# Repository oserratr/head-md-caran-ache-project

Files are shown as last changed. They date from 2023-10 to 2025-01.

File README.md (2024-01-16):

# Future of Drawing - Discovery Process

Discovery est un jeu qui donne un nouveau regard sur la pratique du dessin. Guidé par le sens du toucher, il explore la collaboration entre l’objet et le joueur dans un processus de création.

# Process

## 2023-10-19 to 2023-11-01

*Quelques mots clés*
**Expérience sensorielle - Narration - Liberté d'interprétation**

### Point de départ

J'ai commencé a me demander ce que "AI Assistant" m'évoque dans le projet via une mindmap.
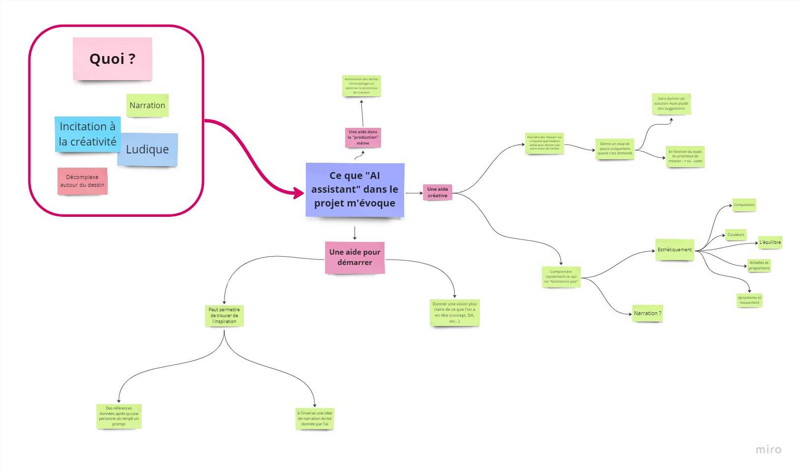
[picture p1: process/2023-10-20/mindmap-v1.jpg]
mindmap


### Public

QUI?
Personnes voulant apprendre, mais stress de ne pas le faire de la "bonne façon" (selon une idée préconçue du dessin),
Complexe par apport a certaines maîtrises du dessin,

POURQUOI?
Rendre le dessin accessible
Décomplexer autour de la pratique du dessin
Expérience sensorielle différente

CONTEXTE
Dans un cours d’initiation au dessin,
Dans un moment calme, chez soi

Le brainstorming m'a permis d'établir un plan de recherche de 3 différentes façons.

### Recherches en ligne sur les pratiques du dessin

**Quels sont les fondamentaux de la pratique du dessin ?**

Sur reddit et d’autre pages web, ont trouve différentes listes que la communauté active sur la pratique du dessin donne en guise de “guide” pour débutant : proportions, couleurs, perspective, anatomie, lumière, volume...

Mais également une distinction de l’apprentissage du dessin traditionnel (papier) et digital : la volonté de structurer son apprentissage, d’apprendre “proprement” la pratique du dessin, sont des éléments récurrents que je retrouve dans les témoignages sur reddit. Ces personnes sont néanmoins limitées sur les moyens techniques, etc...

Une question récurrente est aussi amenée par les internautes a propos d’un certain “ordre” a respecter dans l’apprentissage.

**Quels sont les peurs par apport a la pratique du dessin ?**

Sur la partie focalisé sur les témoignages de personnes se mettant la pression pour faire quelque chose de beau et de la bonne manière j’ai pu remarqué des éléments récurrents : 
- Volonté d’impressionner les gens, d’être validé par la   communauté artistique
- Peu de confiance en soi, comparaison avec l’entourage ou autres artistes qui peu démotiver, pense que son évolution n’est pas assez grande, attente d’un certain niveau considéré par la personne comme étant le “minimum”
- Peur de finir une œuvre et d’échouer, de ne pas être a la hauteur des attentes en therme d’esthétique et de technique, refuse catégoriquement de se lancer pour ne pas produire de “mauvaises choses” 

**Liens d'articles et forums**
- https://www.reddit.com/r/ArtistLounge/comments/ki3zvz/what_would_be_a_list_of_drawing_fundamentals_and/
- https://homesthetics.net/what-are-the-fundamentals/
- https://www.reddit.com/r/IWantToLearn/comments/4ws0wj/i_was_wondering_about_the_fundamentals_of_drawing/
- https://www.youtube.com/watch?v=qpqEE9yU474&list=PLDHJ4RxK-8Tgt-AmgLSdkgdhjL_RS5wrE
- https://www.reddit.com/r/ArtistLounge/comments/kljwdq/why_am_i_so_bad_at_art/

### Recherches en ligne sur les retours haptiques

Plusieurs types de retours haptiques :
- Simule de façon réaliste l'interaction avec un objet via : la texture, le poids, la résistance, le frottement de l'objet
- Un retour haptique qui limite le mouvement : par exemple dans une simulation de conduite de voiture, un volant qui vas être limité dans la vitesse d'exécution du mouvement
- Un retour haptique "actif" qui vas tout simplement être déclenché par une action/mouvement : par exemple dans les jeux vidéo pendant un combat avec un pnj sensation a chaque collision + ou - fortes

### Expérimentations 1 (2 minutes pour chaques parties)

#### Partie 1 : Dessiner au toucher

Dessiner avec un objet dans la main sans le regarder (uniquement reconnaissance au toucher).

*Observations*
- Dessine en plusieurs étapes : au début la forme globale et ensuite certains détails
- Mouvements plus "décomplexés"
- Pas d'attentes/de déceptions sur le dessin final
- Certaines personnes essayes de trouver quel est l'objet avant de le dessiner
- Certaines vont utiliser en même temps leurs souvenirs et le tactile si il reconnaissent l'objet > Avaient l'air "rassuré"

La plupart des personnes n'ont pas utilisé les 2 minutes.
#### Partie 2 : Dessiner de façon classique

Dessiner avec l'objet devant soi en ayant la possibilité de le manipuler, de le regarder.

*Observations*
- Plus de concentration sur l'objet que sur le dessin
- Volonté de le reproduire en fonction de son positionnement, orientation...
- Volonté d'aller dans les détails de l'objet, d'ajouter des ombrages
- Moins de manipulation de l’objet, concentration sur une seule perspective

La plupart des personnes ont utilisé les 2 minutes.

### Interviews

*Quel est ton rapport au dessin ?*
- L’ensemble des personnes interviewer ont commencé le dessin jeune / très jeune : graffiti, dessin a l’école (maternelle, primaire, etc...), activité ludique pour les enfant, concours de dessin, decalcage
- Arrêt de la pratique du dessin pendant un certain temps (souvent entre le collège/lycée)
- Reprise de la pratique par envie, par ennui,
- Pas évident de trouver son propre style graphique,
- Pression par apport au dessin et aux autres

*A quels moment dessine tu ? Dans que contexte ?*
- Pratique de différentes manières : par ennui, professionnellement,  gribouillages sur n’importe quel feuille, par envie, inspiration du moment, ne se limite pas qu’au dessin mais aux arts créatifs, extérioriser, dessiner des souvenirs, fortes émotions, défis/challenges techniques...

*A quels moment dessine tu ? Dans que contexte ?*
- Quels sont selon toi les "critères conventionnels" pour qu'un dessin soit réussi ? Est-ce que tu essaies de les appliquer? Et pourquoi ?

*A quels moment dessine tu ? Dans que contexte ?*
- Subjectif, pas de dessin réussi ou non : doit plaire d’abord a sois même, pas de catégories spécifiques, dessiner au feeling, être fière de son dessin spontanéité. Définition de ces propres critères.
- Pas de manière de dessiner, sauf dans filière très académique. Liberté, assez fort dans le dessin, chacun peut avoir son style, chacun peut faire comme il l’entend.N’essaye pas d’appliquer ces codes académiques.
- Pour des commandes “professionnelles”, certains critères sont parfois a respecter en fonction de cette dernière : proportions, niveau de réalisme en s’appuyant sur des images de références, bon choix de couleurs, beau ombrages, tracées droits. Exemple de la main : importance du réalisme de sa posture, etc...

*Que ressens tu si ton dessin ne correspond pas à ce que tu envisageais?*
- n’anticipe pas ce qui vas être dessiner, totalement freestyle, toujours les même gribouillis et lettres, pour passer le temps, s’attend souvent au résultat que ça va
être, pas d’étonnement spécifique sur le “résultat final”
- frustrations, déception, perfectionnisme, blocage sur détails, motivation pour s’améliorer, pudique sur le dessin en question...

### Prototypage

*À partir de cartes tirées*
**Roller - Color sensor - Wording - Too eager**

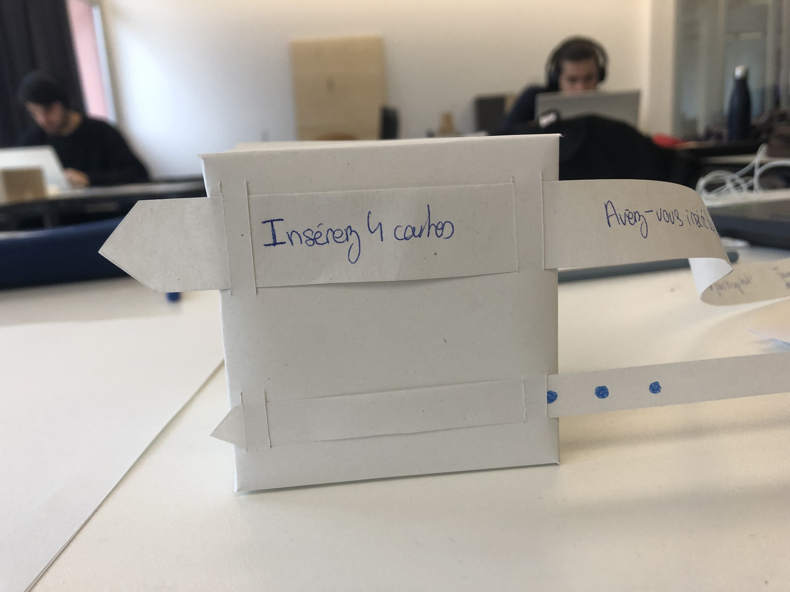
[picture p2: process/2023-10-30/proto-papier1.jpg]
proto1

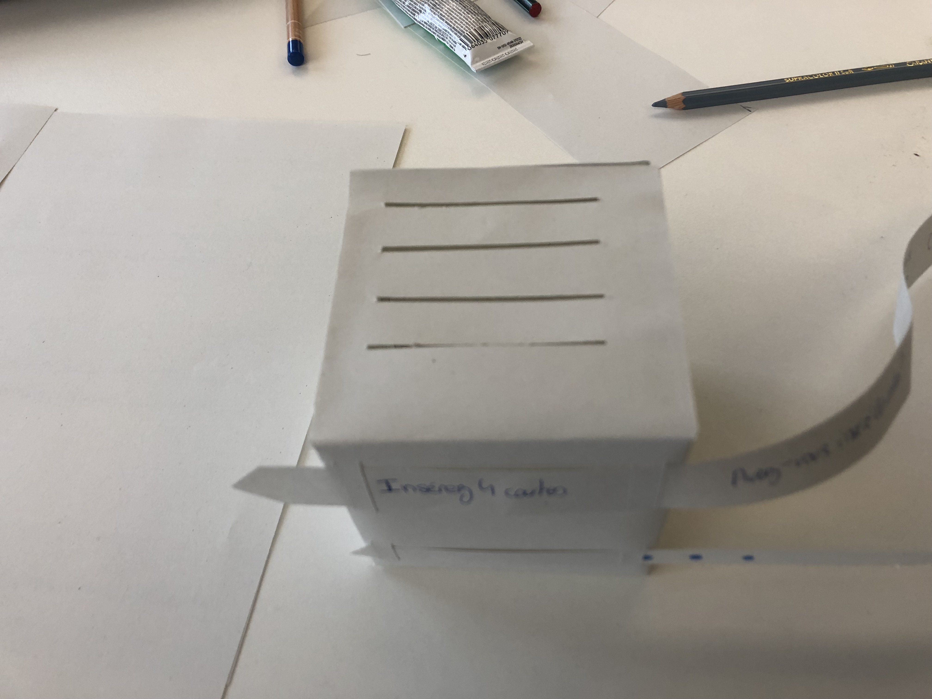
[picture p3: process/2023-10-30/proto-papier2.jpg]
proto2

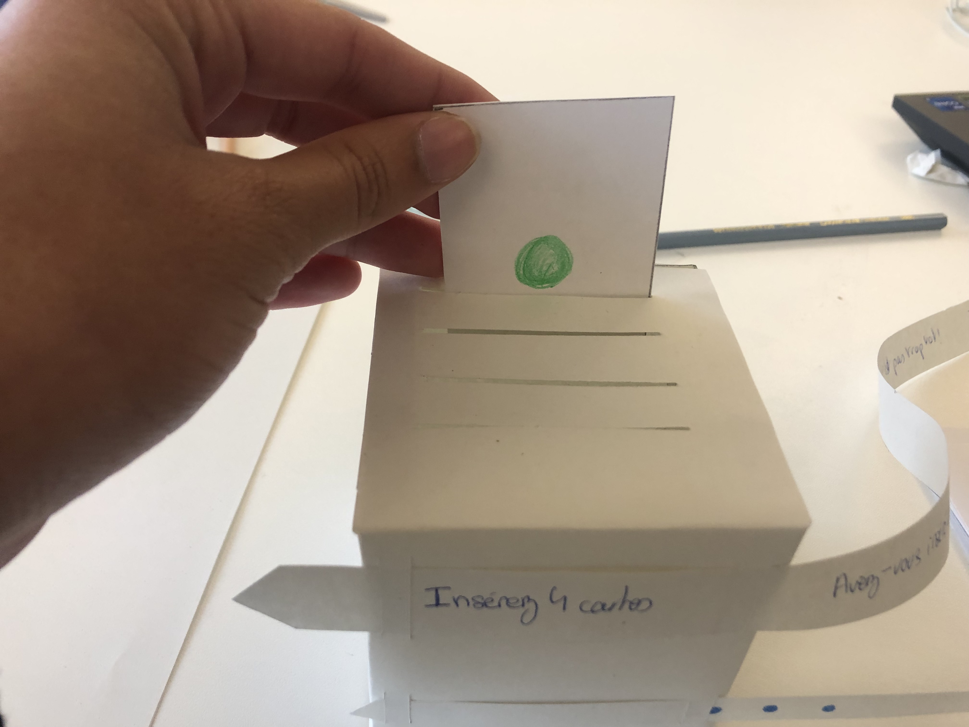
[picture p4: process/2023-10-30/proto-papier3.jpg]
proto3

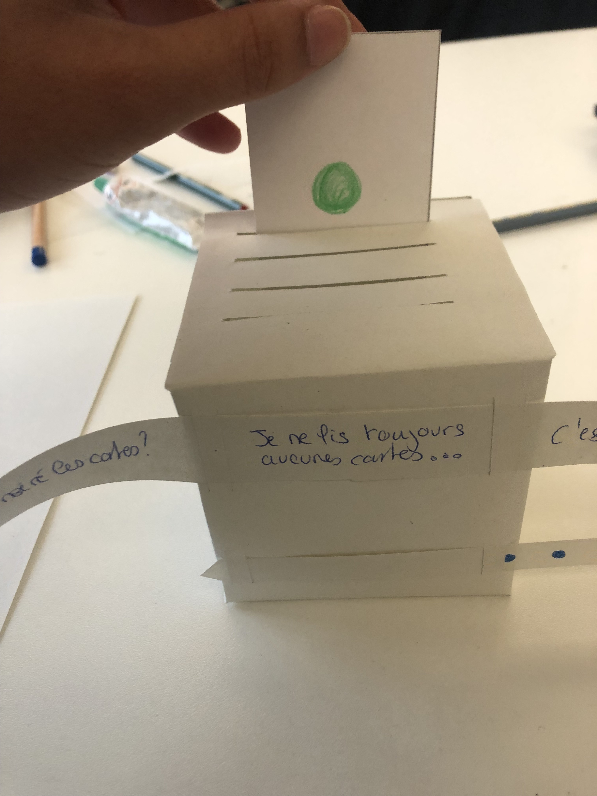
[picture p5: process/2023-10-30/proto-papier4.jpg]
proto4


Un objet qui lirait plusieurs cartes "couleur" que l’on pourrait insérer dans un boîtier qui écrirait sur n'importe quelle surface un poème en le tenant comme un gros rouleau de peinture.

### Premières intentions d'interactions

-> Création de 2 prototypes papiers :

    -> Le premier suite au tirage de cartes (to eager, color sensor, roller, wording) : Un objet qui lirait plusieurs cartes que l’on pourrait insérer dans un boîtier qui ferait de l’écriture en le tenant comme un gros rouleau de peinture. On pourrait choisir via des boutons la typo et au aurait un retour visuel sur les cartes tirées. 

    -> Le deuxième en rapport avec la première intention suite aux recherches menées + cartes tirés (sloppy,pallette): Un objet qui crée une narration de façon aléatoire et divise chaque partie en X en fonction du nombre X de joueur. Chaque joueur dessine sa partie de la narration avec des indices révélé de façon haptique pour faire une grande fresque collaborative. La machine est négligente et peut donner 2 fois la même partie a des joueurs.
1.
*Mots clés*
**Vibrations - Draw - Sloppy - Palette**

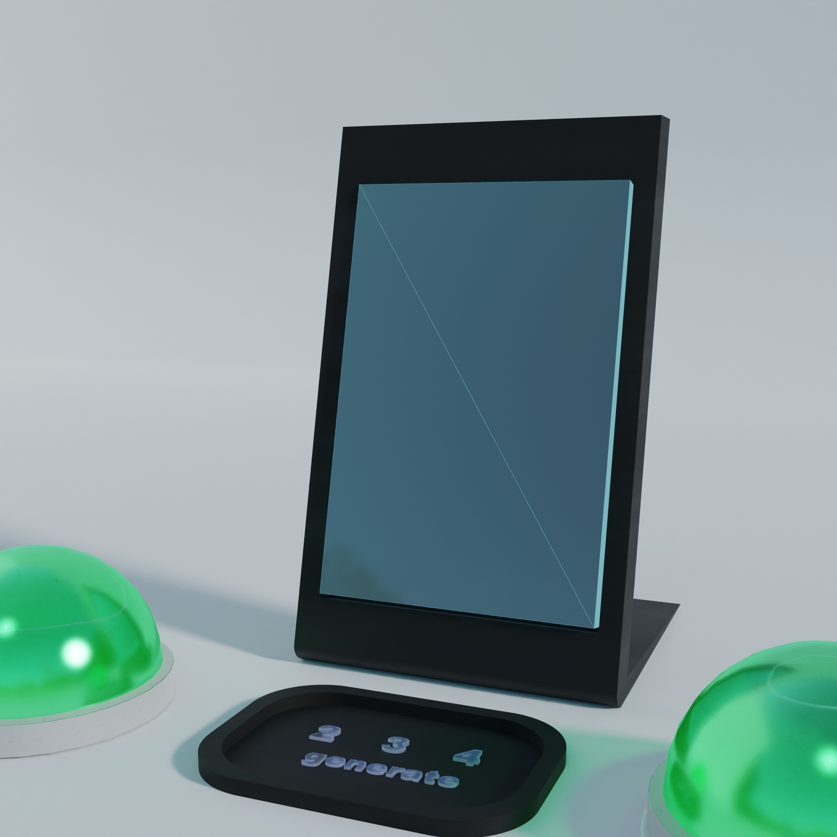
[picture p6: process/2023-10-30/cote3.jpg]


Un objet qui crée une narration de façon aléatoire et divise chaque partie en X en fonction du nombre X de joueur.
Chaque joueur dessine sa partie de la narration avec des indices révélé de façon haptique pour faire une grande fresque collaborative.
La machine est négligente et peut donner 2 fois la même partie a des joueurs(par exemple).

2.
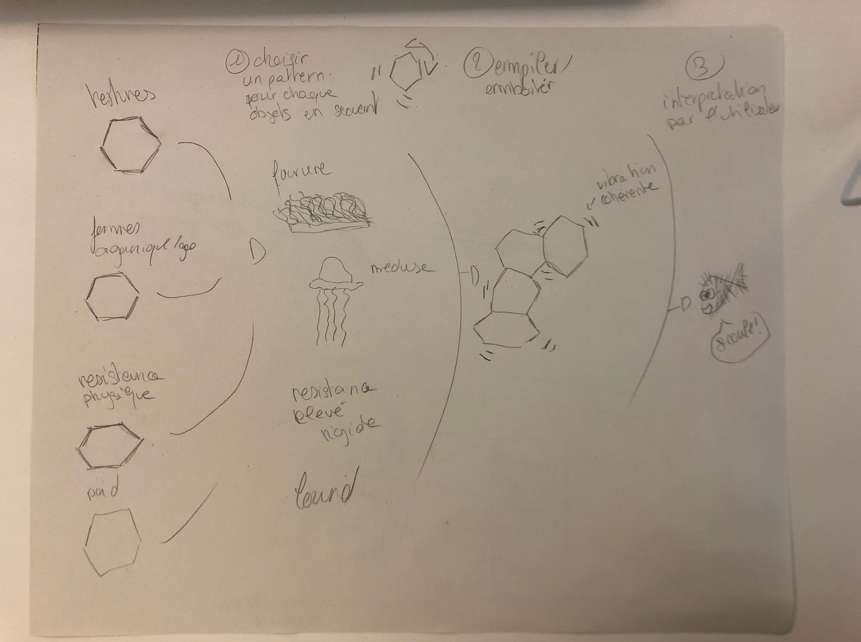
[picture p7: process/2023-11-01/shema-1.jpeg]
proto5


Un objet ayant différents types : texture, poids, forme, résistance / physique. Qui inciterait à l'utilisateur de choisir un partern qui lui plaît dans chaque type d'objet (en le secouant). À la fin du choix, il assemblerait les différents objets pour créer une seule vibration cohérente qui laisserait place à l'interprétation de l'utilisateur, et ainsi, qu'il puisse mettre sur papier.

3.
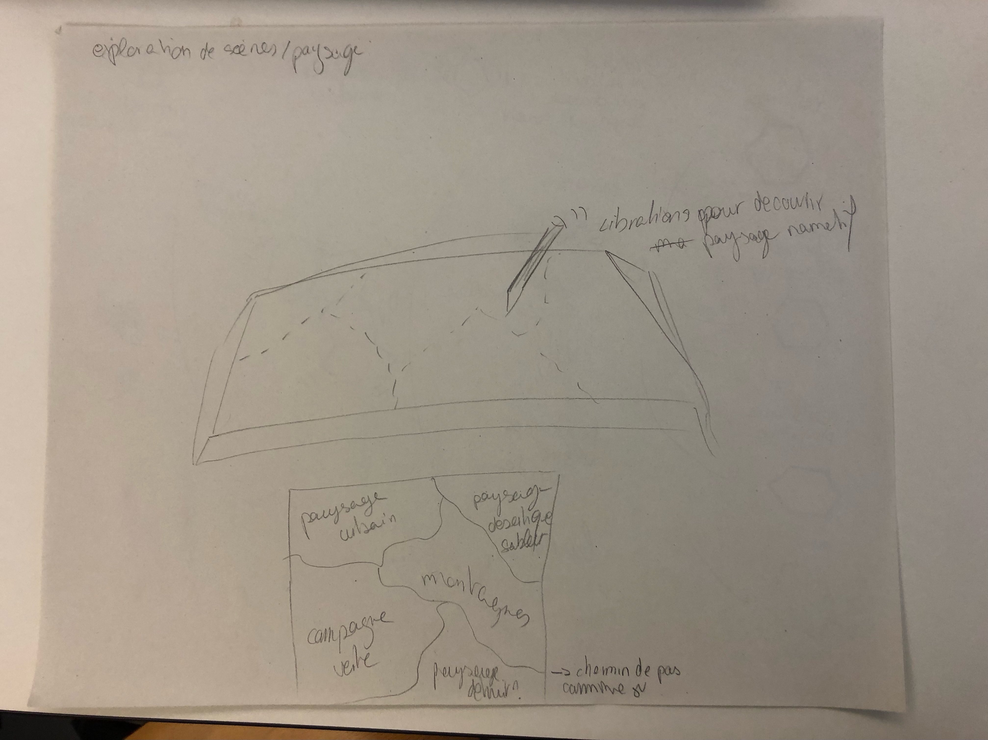
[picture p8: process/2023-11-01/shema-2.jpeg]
proto6


Un objet qui pourrait être enfilé autour d'un stylo/crayon, ou être un stylo/crayon qui sur la base d'un paysage va traduire en vibrations les sensations que l'on peut ressentir dans cet environnement. (chasse au trésor, jeu du chaud-froid)
Et pourquoi pas laisser l'utilisateur manifester comment il interprète cet environnement via le dessin ou l'écriture.

## 2023-11-07 to 2023-11-12

*Quelques mots clés (mise à jour)*
**Expérience sensorielle - Narration - Liberté d'interprétation - Création intuitive grâce à un guide**

### Etre guider de différentes façons pour dessiner
- être guider par une combinaison de gestes comme dans un jeux pour faire de la musique,
- relier des points en faisant des additions (cahiers de dessins pour enfants),
- chenille version dessin (chaque personne dessine dans le dos de la personne devant),
- relier des points en faisant des additions (cf livres de vacances pour enfants),
- guide lumineux 

### Perturber le dessin de la personne
- bouger la feuille dans une direction de façon aléatoire et spontanée
- bloquer la vue de façon aléatoire et spontanée
- faire des mouvements brusques à coté
- deplacer le stylo pendant un bref instant

### Idéation, prototypage et user journey

1. Histoires cachées
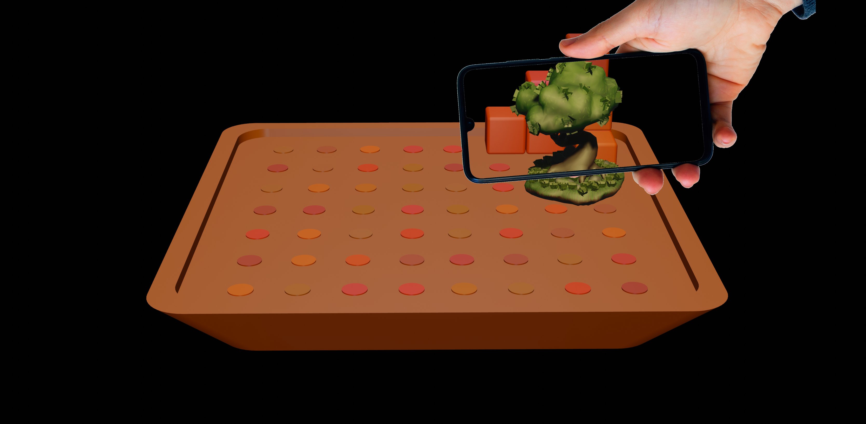
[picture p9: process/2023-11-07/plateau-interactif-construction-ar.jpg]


Concept autour de la construction du type lego/kapla sur une tablette haptique qui guide l'utilisateur sur les différents endroits qu'il explore en interpretant lui même sa propre narration.

2. Objet caché
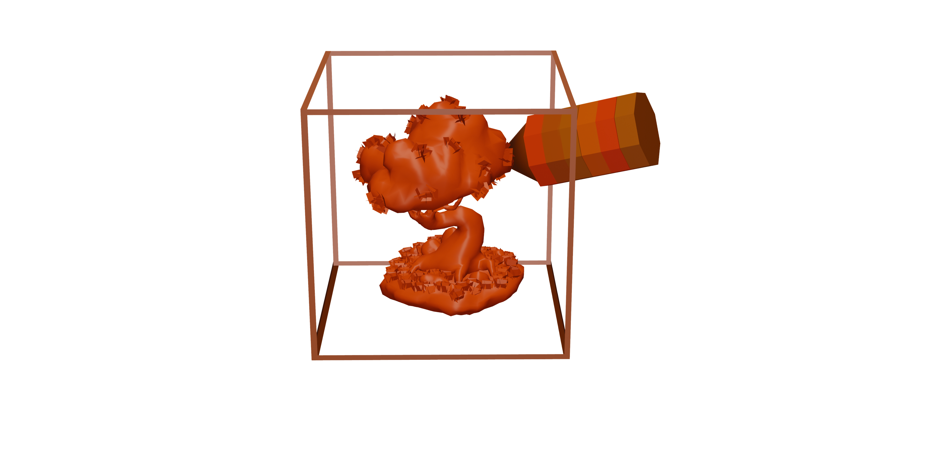
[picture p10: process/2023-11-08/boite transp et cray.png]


Concept autour de la resistance d'un objet invisible via un stylet haptique.

### Paper prototype des premieres idées

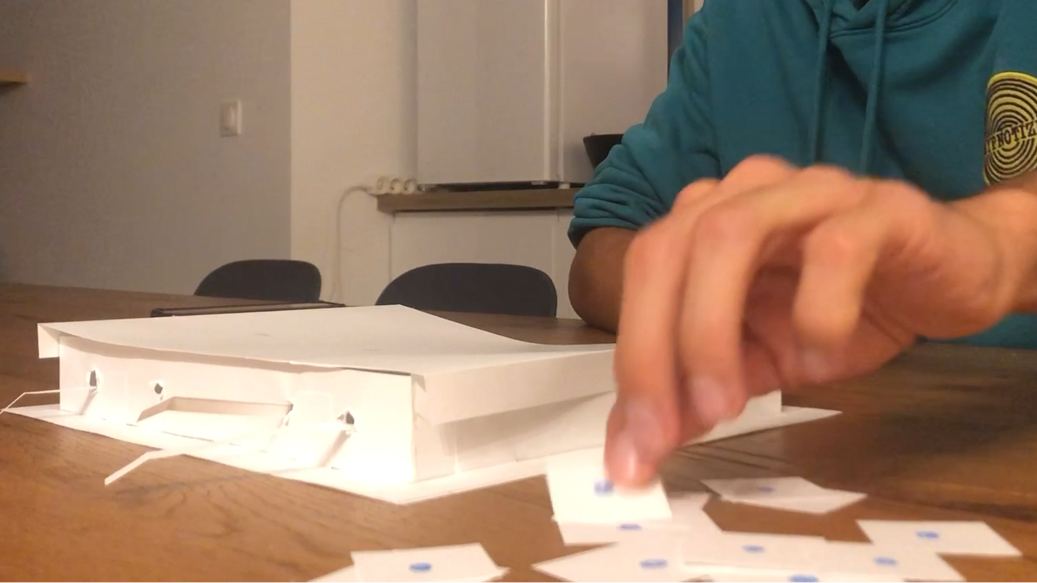
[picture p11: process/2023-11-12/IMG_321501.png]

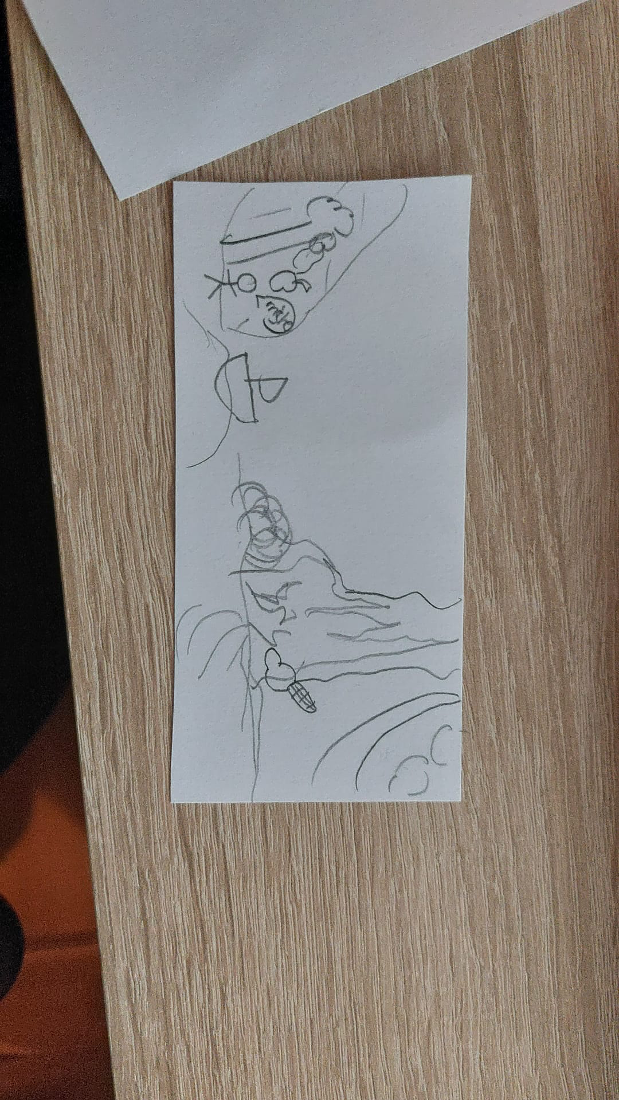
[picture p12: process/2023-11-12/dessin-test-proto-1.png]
proto7

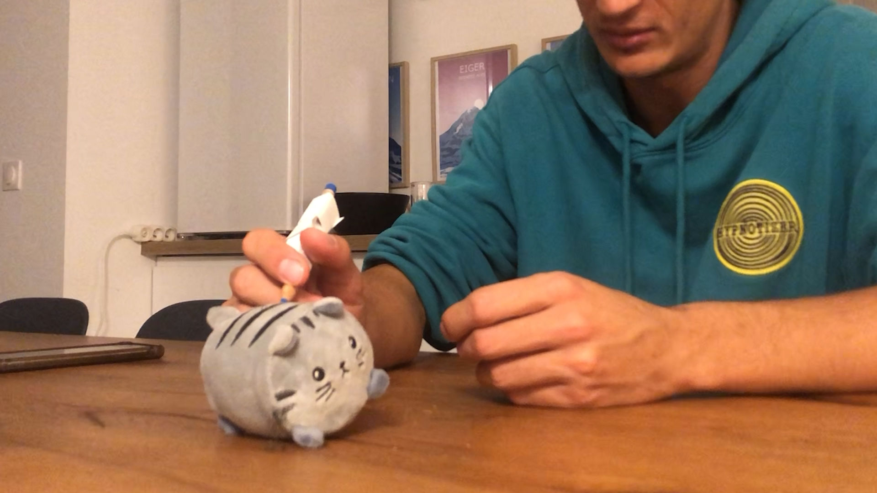
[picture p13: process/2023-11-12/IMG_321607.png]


User test m'as permis de comrpendre que mes prototypes papier n'etaient pas bien pensés, que les users journeys etaient trop complexe pour un resultat pas génial. Les feedback après explications etaient constructifs : trop compliquer de trouver de l'inspiration pour cree une histoire uniquement avec des cubes tous identiques, mauvaise interpretation du deuxième prototype, echec du prototype papier.

## 2023-11-13 to 2023-11-14

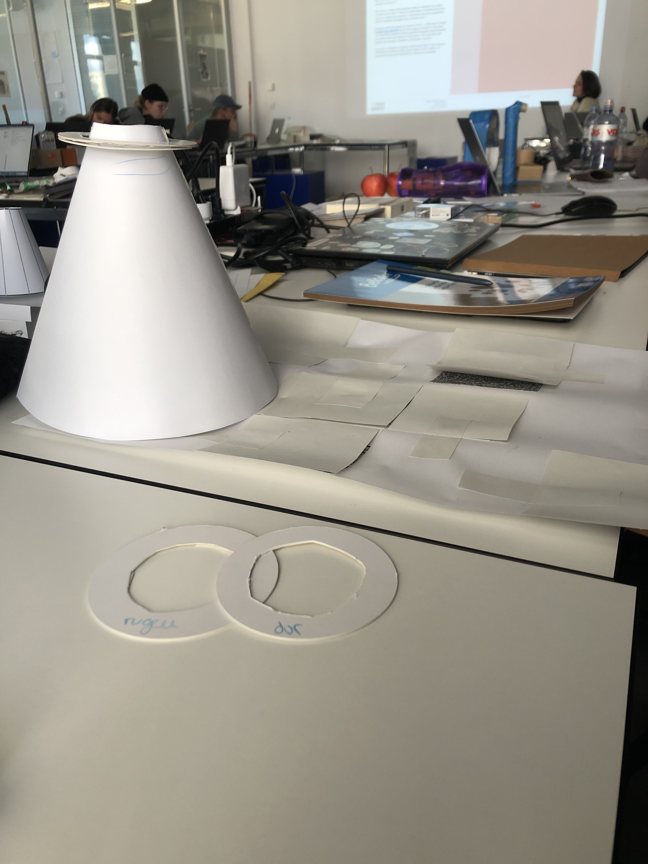
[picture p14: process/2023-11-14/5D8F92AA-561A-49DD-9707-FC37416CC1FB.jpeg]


### Pitch

Interagir avec un espace qu'on assemble mais qu'on ne connais pas, le découvrir et le dévoiler via des vibrations tout au long du voyage.

### Concept

L'utilisateur choisit les anneaux qu'il finit par assembler comme un "totem" sur l'objet (input), qui, en fonction des combinaisons choisies générer un paysage que l'utilisateur doit découvrir et dévoiler. Pour cela, il devra se balader avec l'objet sur un canva (feuille) et jouer avec les vibrations pour trouver les endroits intéressants. Une fois trouvé, il pourra attendre et contempler cette partie du paysage à la fois avec des vibrations qui simuleraient les textures, ainsi qu'avec le dessin qu'effectue l'objet. L'utilisateur peut continuer jusqu'à ce qu'il ne ressente plus de vibration sur tout le canva.

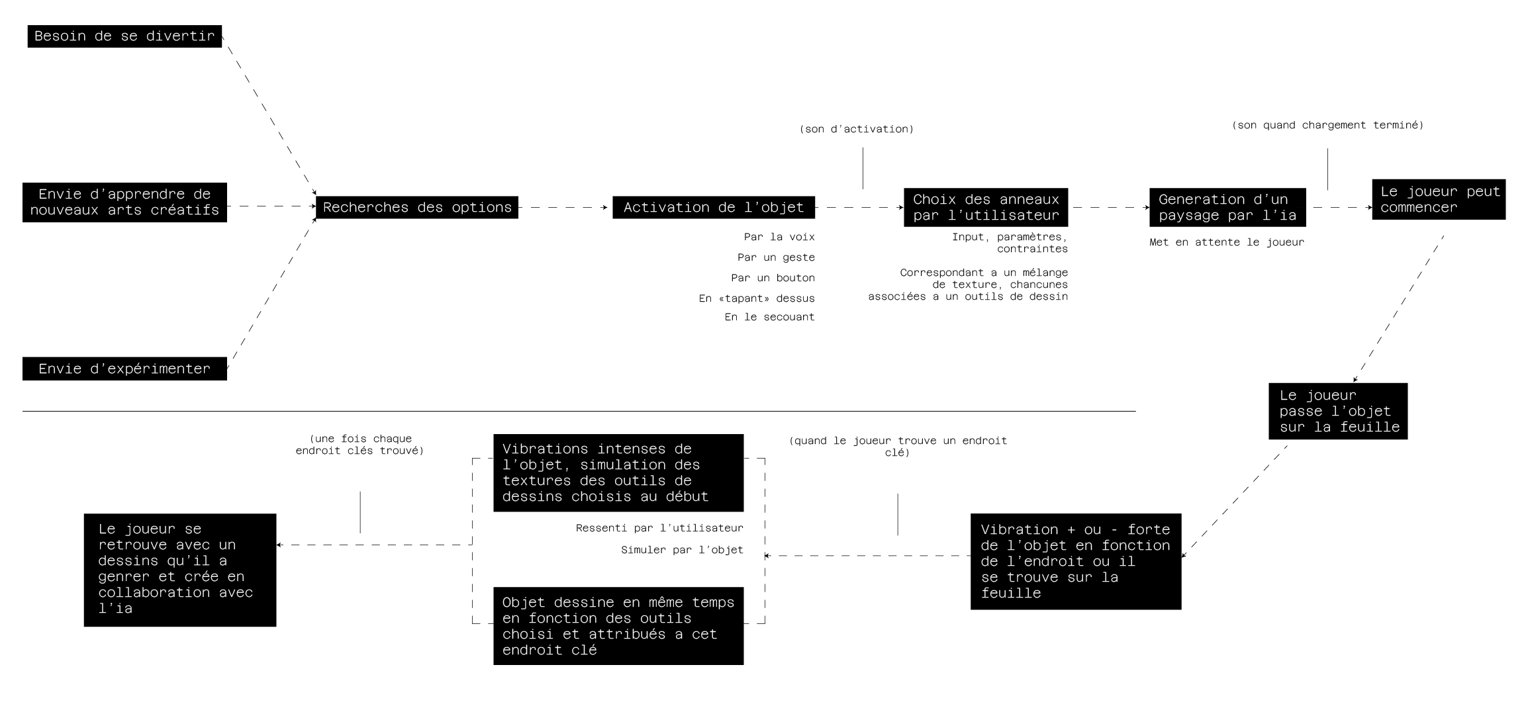
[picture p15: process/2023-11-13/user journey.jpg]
user journey of prototype 1


### Retours de Laure

* Revoir l'output : avoir un element physique (mieux), que digital (du type AR), plus se tourner vers le drawing machine,
* Redefinir l'utilisation des vibrations,
* Explorer, utiliser les outils de dessins,
* Donner des contraintes a l'IA dans le côté génératif,
* Experimenter (prototype papier) une forme assez large pour une prise avec les deux mains a la fois,
* Definir l'input (ce que definit/donne l'utilisateur)

### User Tests

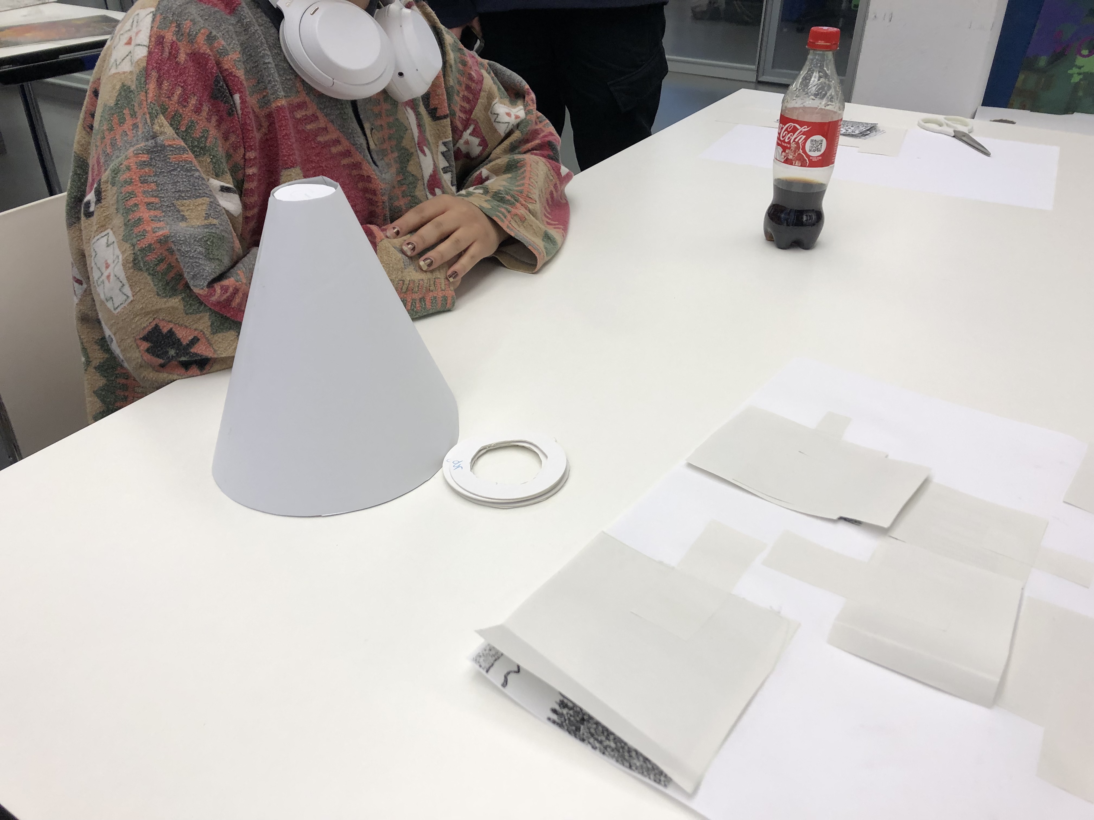
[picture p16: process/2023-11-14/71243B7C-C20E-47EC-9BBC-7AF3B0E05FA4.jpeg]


Bonne compréhension des actions a mener sur le prototype, mais experience très courte au vu de la qualité du prototype papier, l'utilisateur trouve toujour du premier coup les endroits a découvrir sans se balader sur la feuille.

## 2023-11-15

Test de différentes formes de l'objet pour une prise a 2 mains par l'utilisateur.
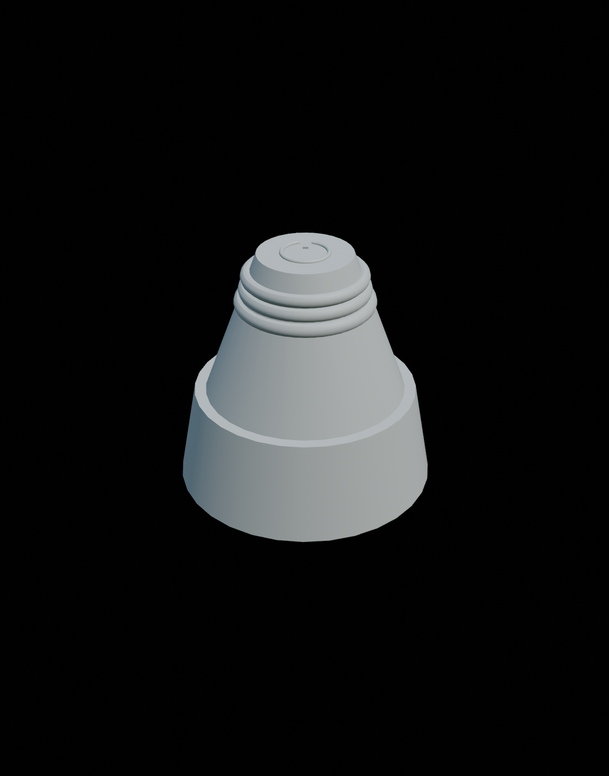
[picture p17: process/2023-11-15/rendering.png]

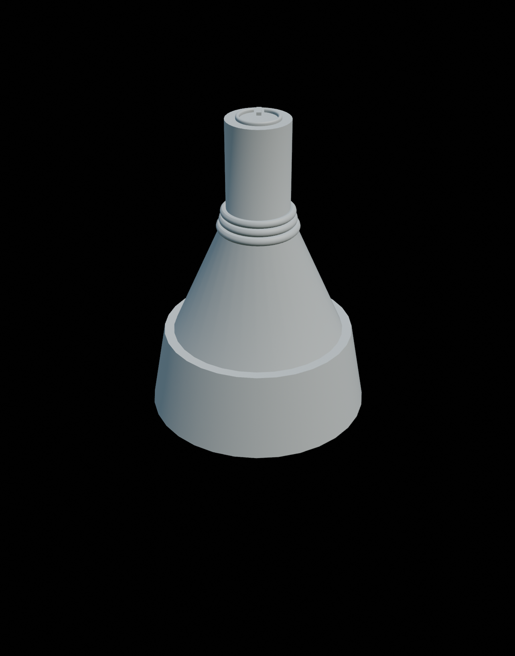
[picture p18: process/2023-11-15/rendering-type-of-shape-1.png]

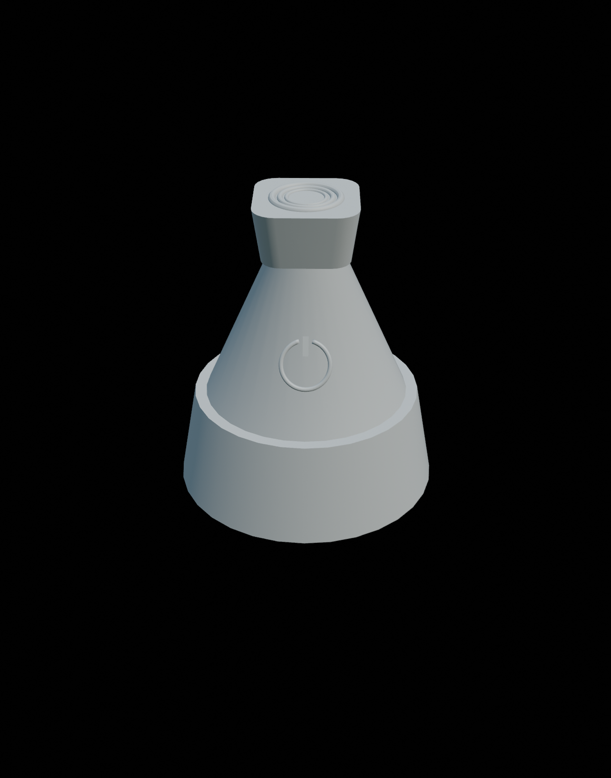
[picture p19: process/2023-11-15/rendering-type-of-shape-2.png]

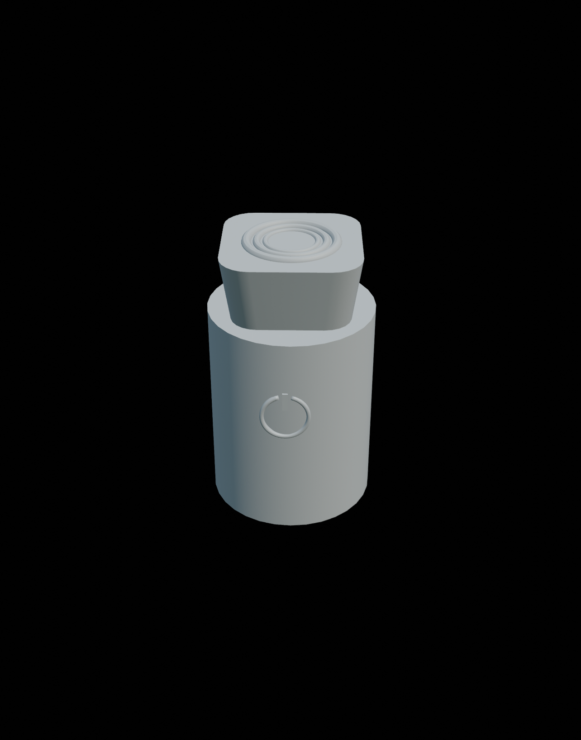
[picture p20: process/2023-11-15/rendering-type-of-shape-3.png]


## 2023-11-27 to 2023-11-29

Test et exercices sur arduino ide et kit electronique :

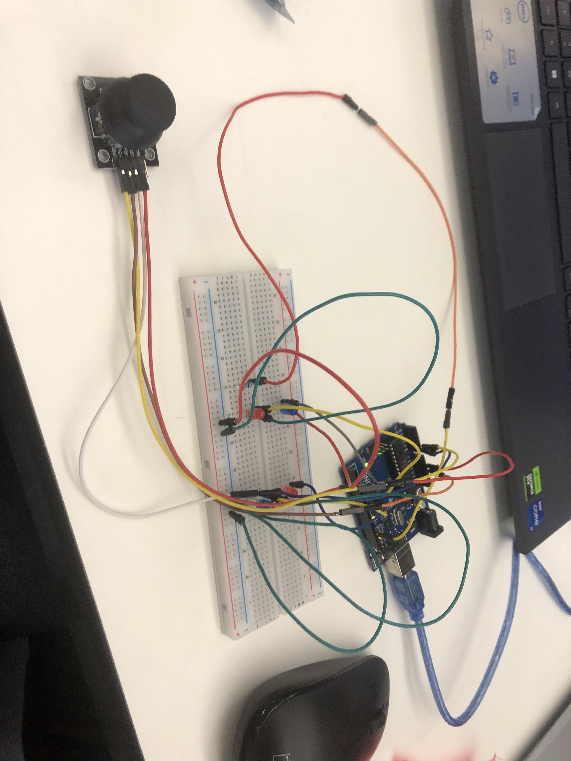
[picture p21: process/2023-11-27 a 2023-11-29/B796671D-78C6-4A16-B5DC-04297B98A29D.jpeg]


## 2023-12-04

### Questions autours du projets (en vrac)

- Est-ce que l'objet se déplace tout seul ?
- Il faut reduire les inputs et redefinir outup
- Il faut redefinir le user journey (une fois que tout ça défini)
- Trouver des formes différentes
- Trouver des matériaux / regarder ce qui se fait (peut aussi être contraignant pour le forme)
- Colaboration ? entre machine et joueurs ? ou entre plusieurs joueurs?
- Definir dimensions du canva ?
- Est-ce que on change l'input avec quelque chose que l'utilisateur dessine ? Est-ce que la machine laisse une trace par-dessus l'input de l'utilisateur ?
- Laisse quel type de trace (texture? dessins sans contours? autre?) ? 

### Pistes de réponses

- Certainement mieux si l'objet se déplace tout seul car réduit les input, permet de ne pas faire trop d'interactions, garder des interactions simples // mauvaise idée techniquement
- Laisse une trace : 
    INPUT : 
    - Anneaux ou dessin (3 ou 4 pièces ?) : definisse ce qui vas être dessiner + trajet/parcours de l'objet
    - Poser main sur objet (ressentir vibrations)
    OUTPUT (TROP?):
    - Feedback sonore (activation objet)
    - Trace, dessin par la drawing machine
    - Vibrations ? (techniques de dessins)
- Mise a jour User Journey

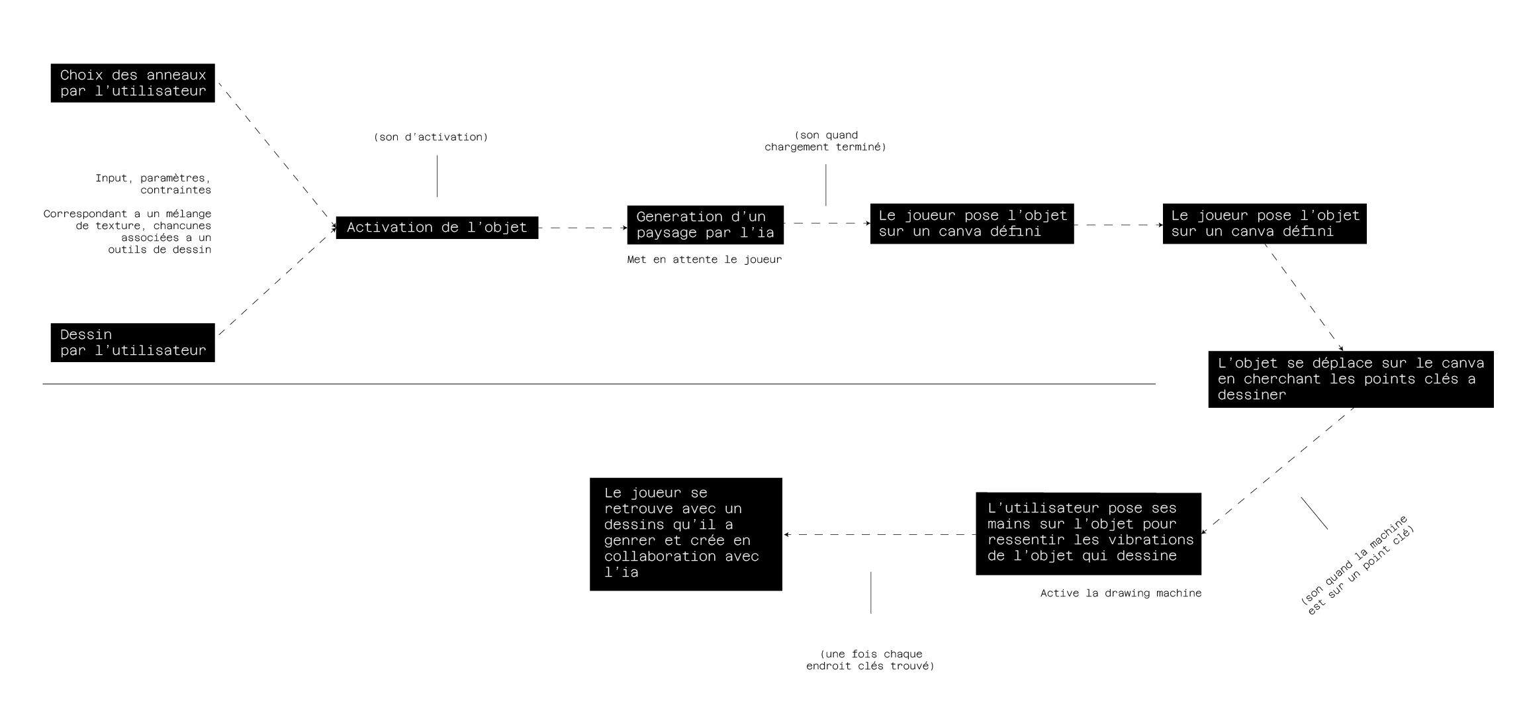
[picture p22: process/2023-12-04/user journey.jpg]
nouvelle user journey


- Pistes de formes possibles :
    - idée forme de champignon

- Recherche de matériaux :
    - Materiel semi-transparent PP : permettrait d'entre-voir les mouvements de la machine 

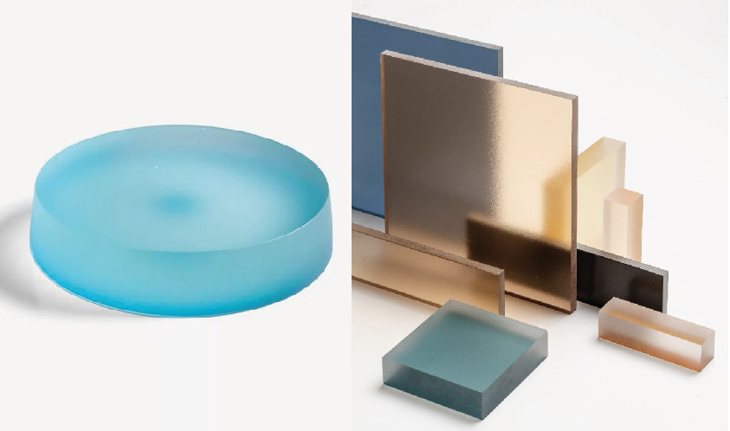
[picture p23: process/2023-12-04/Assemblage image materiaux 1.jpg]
inspiration materiaux 1
    

### Retours sur la réalisabilité du projet

- Pour la partie dessiner en temps réel : utilisation de l'axidraw car trop compliqué de faire drawing machine dans l'objet
- Pour le questionnement sur le déplacement ou non de l'objet : il vaut mieux que ce soit l'utilisateur qui déplace l'objet car trop compliqué de juste faire déplacer tout seul l'objet.
- Pour la partie sur detection d'anneaux (ou peut importe - juste input) : questionnement sur si possible qu'un seul capteur rfid lise plusieurs input en même temps, questionnement sur si possible de faire d'autres output ? 
    - Première alternative : dessiner des couleurs sur le canva qui sont detecter par l'objet. Mais --> perte du jeu de chaud-froid dans la conception du dessin.
    - Faire expérimentations sur le capteur rfid de l'arduino
- Pas abordé coté generatif du projet
- **Idées importantes : coté jeu du chaud froid avec retours sensoriels, et coté generatif**
- Voir si possible de lancer un programme depuis arduino sur l'axidraw
- Capteur de lumière pour savoir si l'objet est posé sur le plateau ou non 
- Mettre des capteurs pour savoir quelles zones sont actives dans la découverte du dessin
- Detournement d'une souris pour savoir sa trajectoire

### Questions suite a débrief

- Est-ce que obligatoire de garder les anneaux ? voir avec la forme de l'objet
- Est-ce que l'axidraw continue de dessiner si l'utilisateur se déplace pendant que la machine dessine ?
    - Possibilité : Continue de dessiner, mais pas de vibrations pendant le temps du dessin
- Indications visuels sur comment positionner l'objet par apport a la feuille : orientation, endroit
- Comment est géneré le dessin ? via une api d'une ia ? ou est-ce que design predefinis ?
- Est-ce que combinaison des différents output ? ou tout séparer ?
- Définir combien d'output ou donne a l'objet ?
- Quel type de fichier envoyé a l'axidraw ? (certainement vectoriel)
- Création d'un plateau de jeu ? 
- Sortie physique du dessin ?

## 2023-12-05

### Objectifs d'aujourd'hui par ordre de priorité

- Simplifier le projet au maximum en gardant les éléments principaux du propos
- Liste electronique device
- Travailler la forme de l'objet (pour ce soir)
- Continuer veille créative sur matériaux

### Simplifier le projet

### En l'état

- Utilisation de l'axidraw pour la partie drawing machine ? Peut être trop conséquent pour le prototype du projet
- Utilisation de filtres de couleurs pour reveler le dessin ? Peut-être mieux ? avec des lumières différentes et des encres de différentes couleures ? + utilisation d'une imprimante ? (pour éviter de faire mecanisme de dessin)
- Garder le concept de vibration pour revéler un dessin. Propos en lien avec les recherches : approche différente du dessin, decouverte sensorielle
- Garder le concept de : je choisi des inputs (à définir) au feeling (permet d'eviter la frustration, et le perfectionnisme dans la réalisation du dessin cf itnerview + experimentations) en donnant X paramètres prédéfinis qui genère un dessin (paysage : pourquoi? / Côté freestyle du dessin cf interview, pas de blocage sur  reproduction d'un environnement de façon empirique pour aller dans les détails : ce qui est souvent une pratique quand on comtemple des paysage pour les reproduire cf recherches sur internet)

### Solutions (a voir si faisable et plus simple)

- Idée 1 : 
    - Choix des input : 
        - Cartes élements de paysages : choix d'un seul input que la personne connait.
    - Vibrations : Trouver tout les points clés du dessin sur un plateau de jeu a reveler grâce a l'intensité de la vibration. Quand point trouvé : Feedback sonore et plus de vibration si utilisateur continue de bouger.
    - Reveler le paysage : Revele le point clé du paysage via un écran avec animations des tracé comme si la personne desinnait.
    - A la fin : récupération du dessin préalablement imprimé ou impression a la tout fin quand la personne a fini de trouver tout les points clés.

### Est-ce que les solutions sont plus simples et faisable ?

- Pour le choix des input : (a mon avis faisable) avec capteur rfid ou ncf ou capteur de couleur. Interpretation de l'id du tag par le programme. Fake IA avec choix random dans bibliothèque de plusieurs dessins deja fait + animation du drawing.
- Le joueur doit poser l'objet sur un endroit donné du plateau de jeu dans une orientation indiquée. Detournement d'une souris sans fil en guise de curseur pour situé l'objet sur le plateau de jeu et suivre ses déplacement. Exploration du plateau de jeu grâce a l'intensité des vibrations. Quand endroit clé trouvé : plus de vibrations + feedback sonore?. Endroit clé activé grace a puce ou capteur ?? **Est-ce que je peux definir les endroits clés directement avec le dessin ?**
- Viens la revelation de la partie du paysage avec l'animation du dessin sur l'écran. (a mon avis faisable)
- Impression envoyé par l'arduino du dessin lorsque tout les capteurs sont desactivés.

### Liste electronique / matériel

- Souris sans fils : https://www.amazon.fr/NOUVEAU-BLUESTORK-Souris-boutons-m%C3%A9tal/dp/B07MQK52ZD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 
- Capteur de rfid **ou** capteur de couleur : capteur RFID deja dans arduino
- Raspberry pi ? (plus performant ?) ou Arduino nano 33 ble sense ? bluethoot ou wifi en fonction de imprimante : https://www.adafruit.com/product/3055 **ou** https://www.pi-shop.ch/arduino-nano-rp2040-connect 
- Vibration motor : https://www.adafruit.com/product/1201
- Controller vibration motor : https://www.adafruit.com/prosduct/2305
- Grand écran : Umprunter au lab media design
- Capteur de luminosité : a voir si compatible avec raspberry mais déja dans le kit arduino
- Un haut parleur : pour feeback sonore peut être suffisant celui arduino mais bruit clair mieux? 
- Imprimante portable wifi : https://ideen-platz.ch/products/thermodrucker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

### Retour liste electronique (MAJ)

- Retour de l'axidraw 
- Souris bluethoot caché dans un objet mobile --
- Programme processing sur ordi (raspberry pi)--
- Detection des zones sensibles avec vibrations--
- Zones activé -> entraine une partie de dessin sur axidraw + desactive la zone + desactive les vibrations le temps du dessin
- Esp 32 et baterie pour alimenté vibreur dans objet--
- https://www.sparkfun.com/products/15663 --

**Shémas éléctrique et physique (pas remis au propre)**

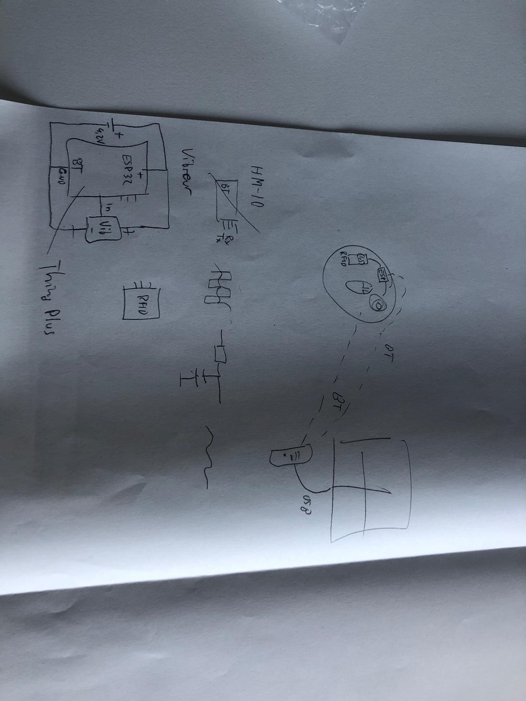
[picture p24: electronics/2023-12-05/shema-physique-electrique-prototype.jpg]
electrique shema


## 2023-12-06

### Références 

Données par Laure :

- Pierre Charpin : https://www.pierrecharpin.com/
- Plexiglas frosted colour : plexiglass semi-transparent pour la partie ou on pose les mains, coloré avec un papier diffu 
- Sabine marcelis
- Patin feutre meuble : en dessus de l'objet pour eviter qu'il raye plateau de jeu

### Sketch

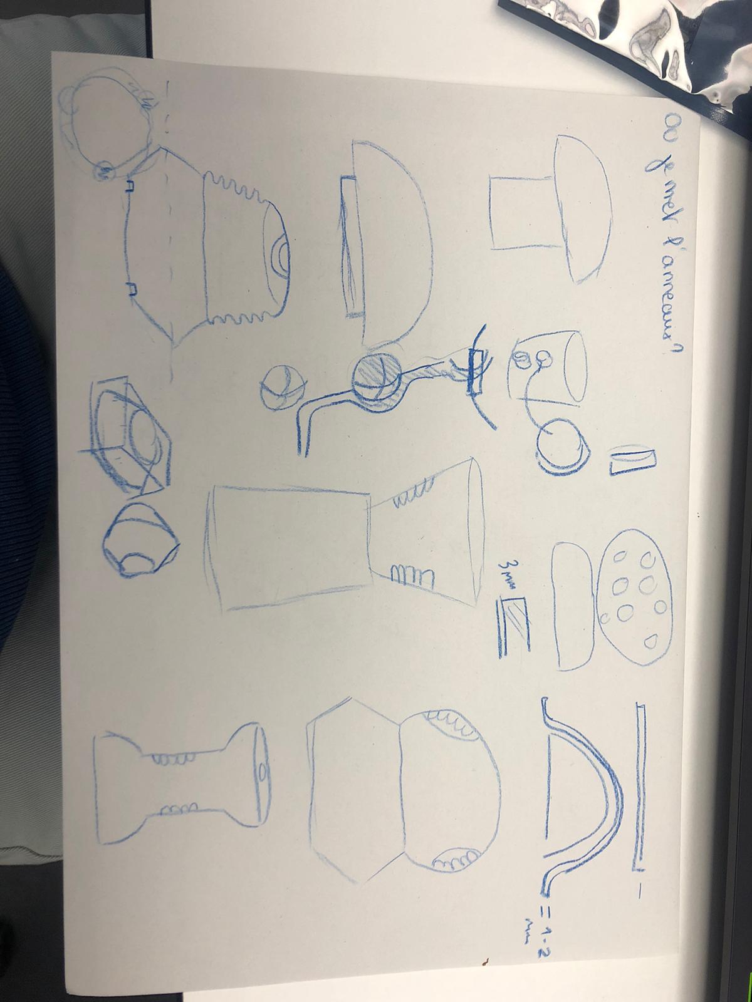
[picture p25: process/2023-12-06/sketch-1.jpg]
sketch 1


## 2023-12-07

### Toutes les étapes pour contruire la chose

### Forme

- Modélisation 3D (Fusion 360)
    - Curseur, pion
    - Plateau de jeu

### Matériaux

- Bois (plateau + socle pion) :
    - CNC
    - Polir

- Plastique (parite haute du pion) :
    - Impression 3D
    - Thermoformage

### Electronique

- Raspberry pi/Ordinateur
    - Code
        - Control drawing machine
        - Bluetooth connexion de l'esp32
        - Détection des deplacements de l'objet
    - Inputs
        - Bluetooth souris
        - Esp32
    - Output
        - Axidraw
- Esp 32
    - Code
        - Intensité vibration
        - Detection de l'input (objet) utilisateur
        - Connexion bluethoot a la raspberry pi
    - Input
        - Rfid tag
        - Moteur de vibration
- Dimensions
    - Pion :
        - 64,7x22,8 mm esp32
        - 5.6mm x 49.2mm x 68.8mm Battery
        - 99 mm x 60 mm x 39 mm souris sans fils
        - 24 mm x 20 mm x 9.8 mm vibrateurs
        - 40 mm x 60 mm capteur rfid
        - 25mm tag rfid
    - Vers axidraw :
        - 85 mm x 56mm raspberry pi

- Cablage
???
- Puissance requise
    - Secteur PC
    - 3.7 v

### Sketch formes

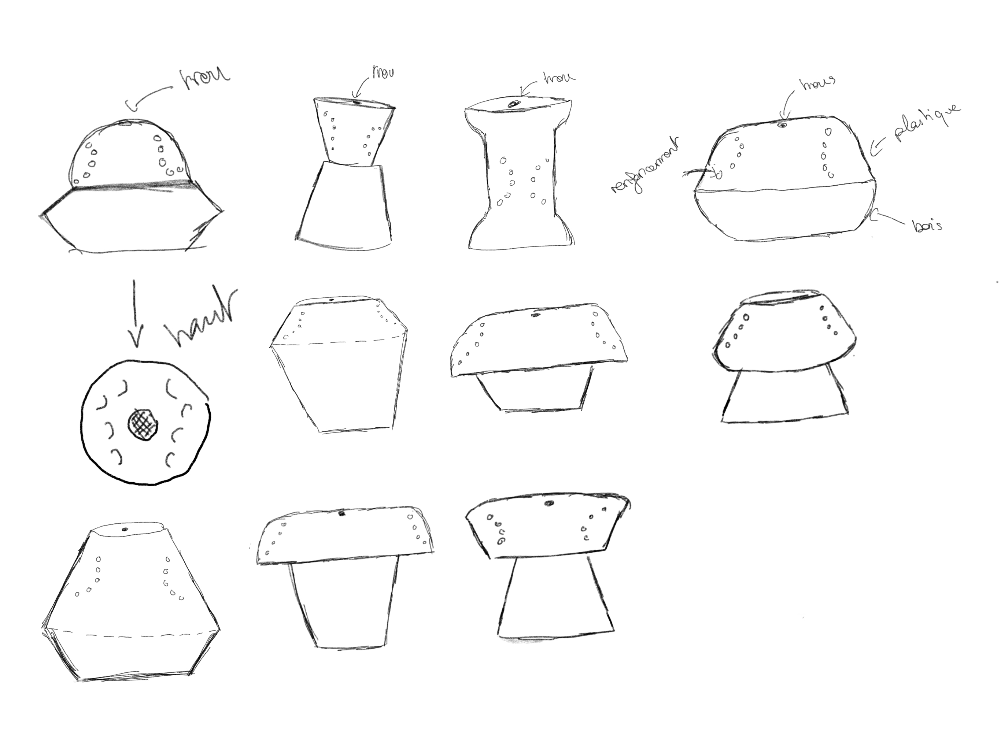
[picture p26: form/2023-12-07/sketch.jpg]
sketch 1


## 2023-12-11

### Sketch formes mise a jour

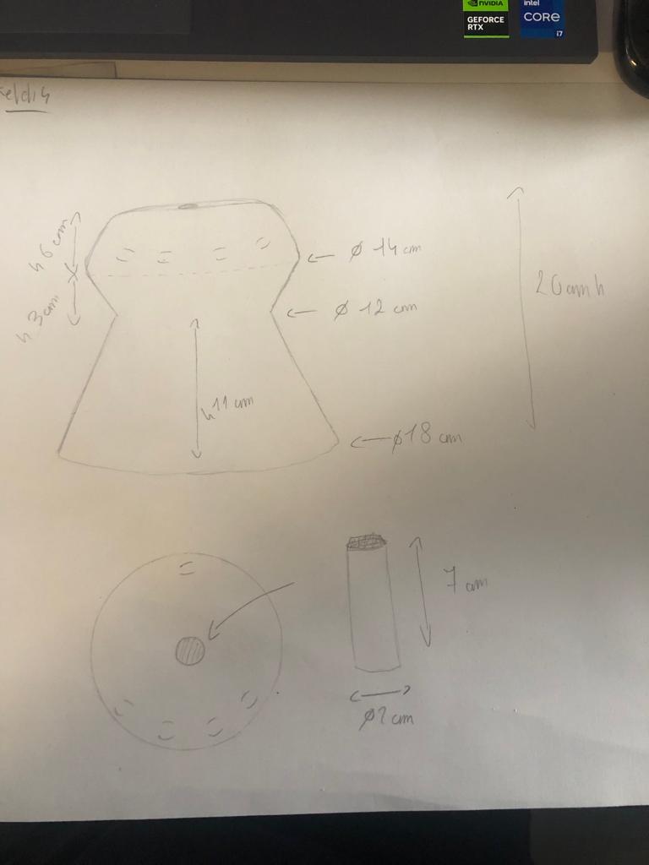
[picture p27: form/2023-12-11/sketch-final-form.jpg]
sketch 1


## 2023-12-12

### Test prints 3D des différentes iterations de formes

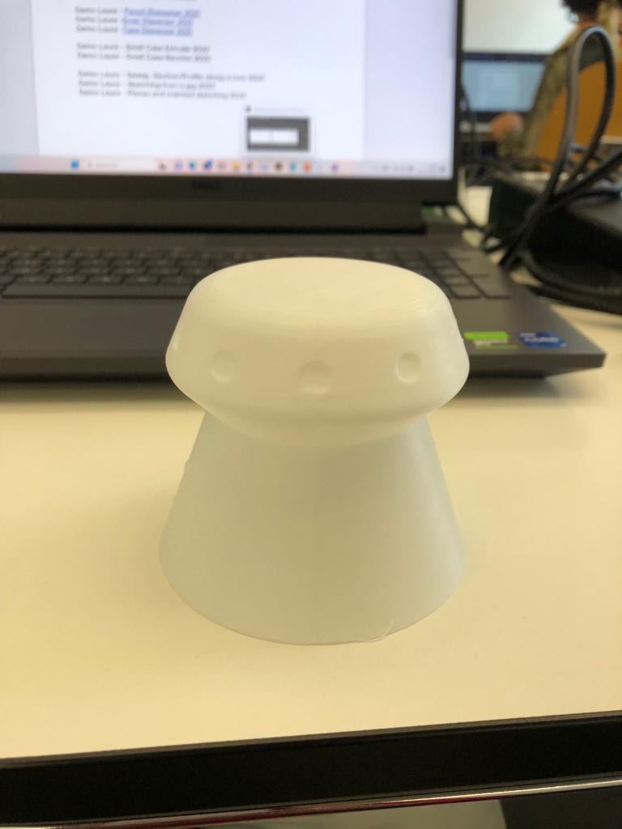
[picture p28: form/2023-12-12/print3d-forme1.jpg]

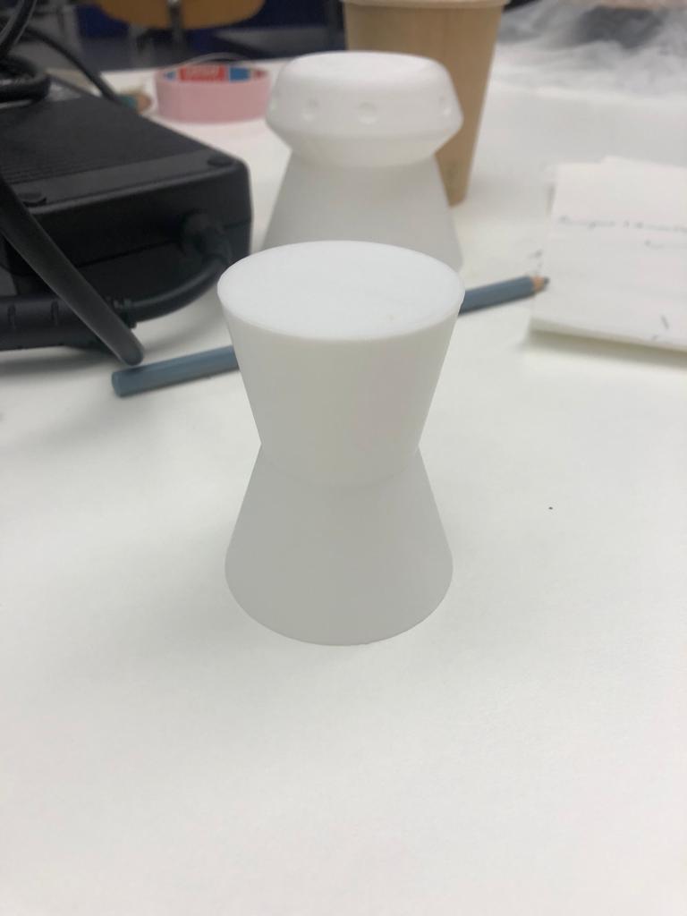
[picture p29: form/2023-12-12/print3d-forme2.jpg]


En 40 pourcent de la taille normal, formes peut concluante sur une prise a 2 mains -> reflexion sur une forme qui se prend uniquement a une main pour plus d'amplitude dans les mouvements quand le bras se balade sur le plateau.

### Captures des dimensions des objets f3D

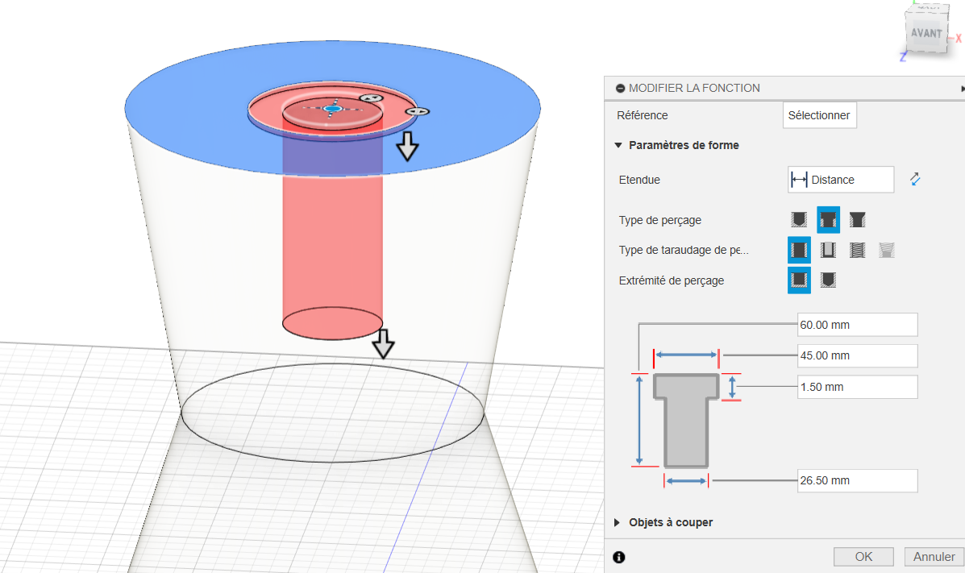
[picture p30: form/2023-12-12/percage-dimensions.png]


### shema physique de l'electronique

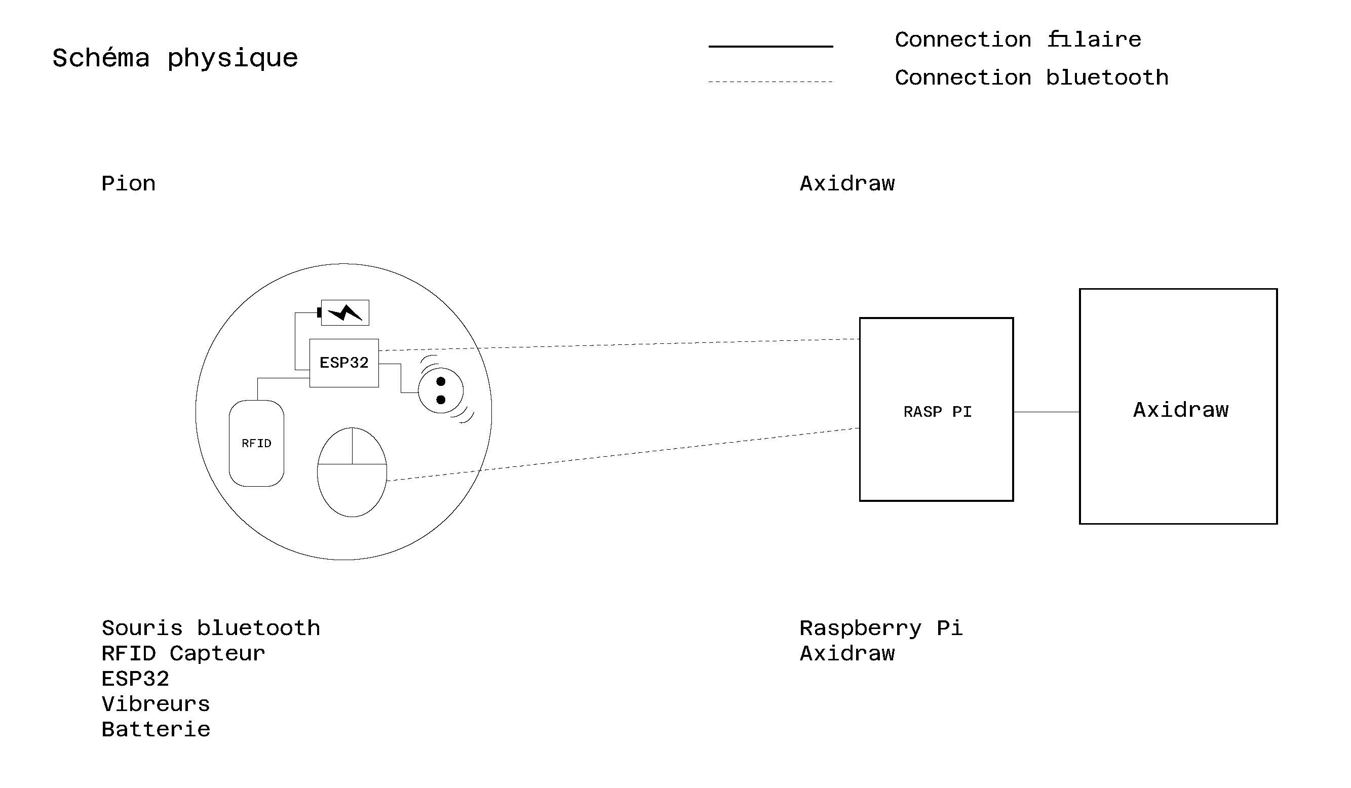
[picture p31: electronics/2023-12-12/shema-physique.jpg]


## 2023-12-14

### Test day

* Ce qui a été testé : prise en main de l'objet, intuitif ?

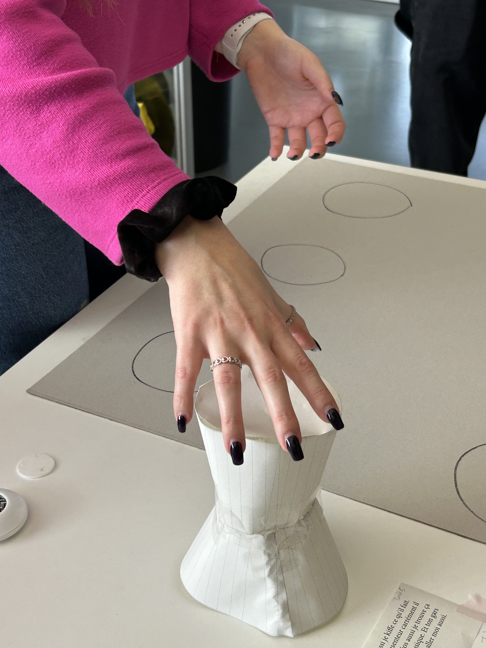
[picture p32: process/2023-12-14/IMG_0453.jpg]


* Résultats :
    * prototypes pas utilisés comme imaginés
    * garder l'idée du manche en haut plus étroit
    * Forme 1 --> trop large pour prise a une main au dessus. Première prise en main generale avec les 2 mains -> pas optimal pour se déplacer sur une grande surface. Prise en main en dessous du champingon
    * Forme 2 --> Prise a deux mains, fait rouler l'objet ?? + intuitif que la forme 1
    * Forme 3 --> Pris a une main au dessus et autour comme gobelet / manche

* Conclusion :
    * La plupart des objets ne sont pas intuitif
    * Revoir les proportions de l'objet
    * Se limiter au diamètre de la paume de la main
    * Faire un manche plus organique, courbé
    * garder reference de la lampe torche pour revelé le dessin

## 2023-12-19

Forme final après les test days :

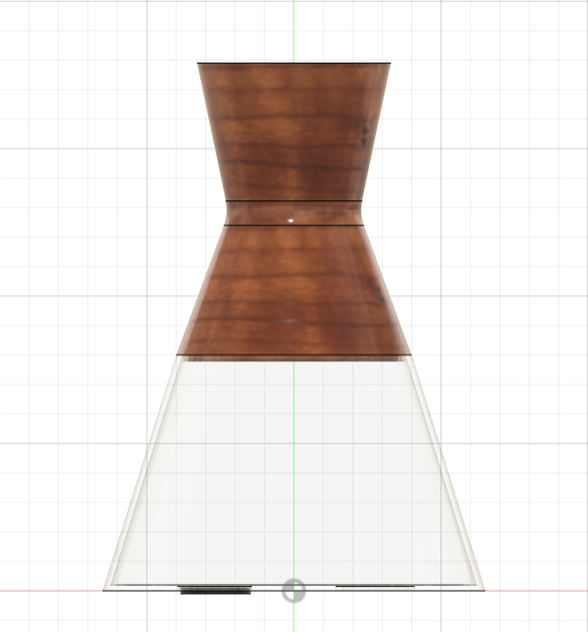
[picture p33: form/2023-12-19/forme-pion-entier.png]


### Text description - Object

### Each part

- A . Pion :
    - 1 . Manche
    - 2 . Socle

- B . Plateau 

### The materials

- A . Pion :
    - 1 . Manche : Bois
    - 2 . Socle : Résine (impression 3D)

- B . Plateau : Bois

### Dimensions

- A . Pion : 179mm hauteur * 130mm diamètre
    - 1 . Manche : 99mm hauteur * 80mm diamètre
    - 2 . Socle : 80mm hauteur * 130mm diamètre

- B . Plateau : a definir

### Description

- A . Pion : objet de naviguation
    - 1 . Manche : partie pour prendre en main l'objet
    - 2 . Socle : partie support de l'objet avec l'electronique dedans

- B . Plateau : support sur lequel naviguer avec le pion

## 2023-12-20

### Liens important documentation

- https://www.aranacorp.com/en/using-an-rfid-module-with-an-esp32/
- https://learn.sparkfun.com/tutorials/esp32-thing-plus-hookup-guide/hardware-overview
- https://www.handsontec.com/dataspecs/RC522.pdf

### Cablage

RFID to ESP 32 :
- MISO (Master In Slave Out): GPIO19
- MOSI (Master Out Slave In): GPIO18
- SCK : GPO5
- CS/SS : GPO23

- GRND : GRND
- 3.3v : 3V3

ESP32 to battery :
- Fil rouge : VBat
- Fil noir : GRND

Vibrator to ESP32 :
- SIG on whatever

- GRND : GRND
- VCC : VBat

### Etapes

- Configurer ESP32 pour bluethoot cf schema physique
- Connecter souris a pc ou rasp pi
- Configurer capteur rfid avec les différents tag + random fichiers vectoriels
- Test envoi axidraw avec rasp pi
- Test envoi axidraw avec rasp pi avec information du tag
- Code sur zone activation en fonction de position de souris
- configrer rythme des vibrations 

## 2023-12-21

Soudures electronique et test de connexion bluethoot a l'esp32 depuis le PC :

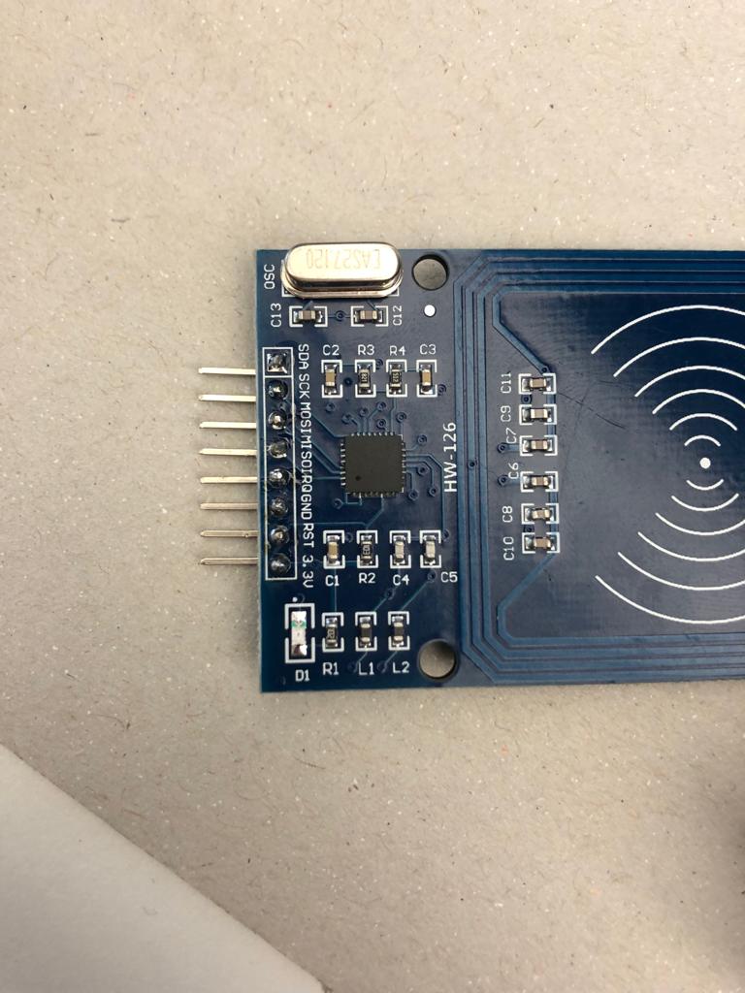
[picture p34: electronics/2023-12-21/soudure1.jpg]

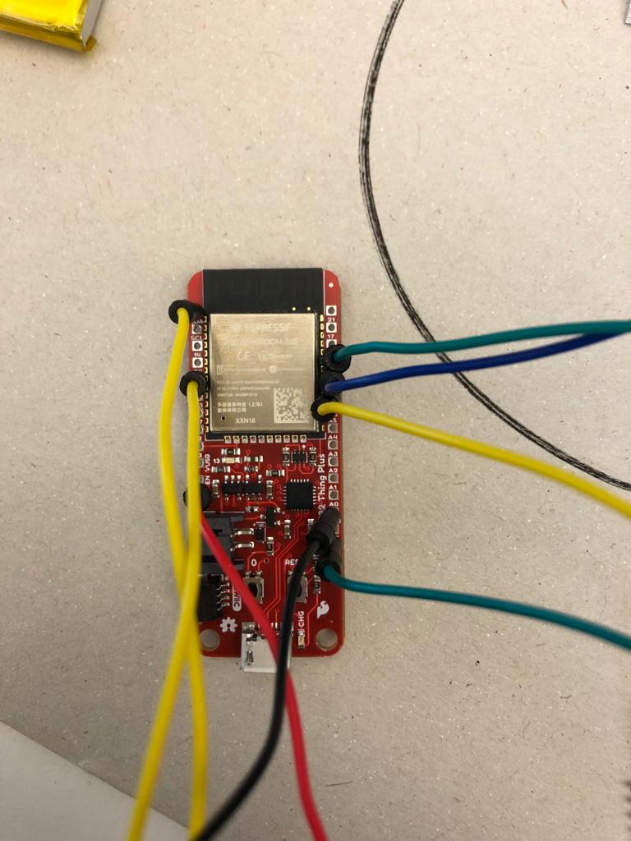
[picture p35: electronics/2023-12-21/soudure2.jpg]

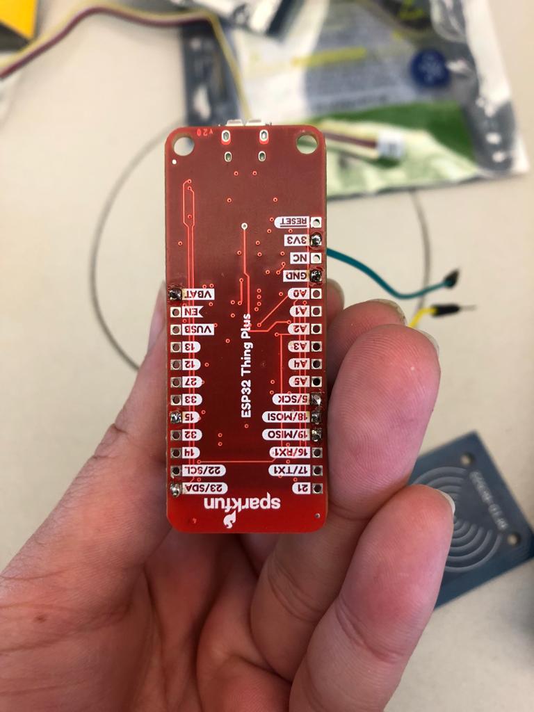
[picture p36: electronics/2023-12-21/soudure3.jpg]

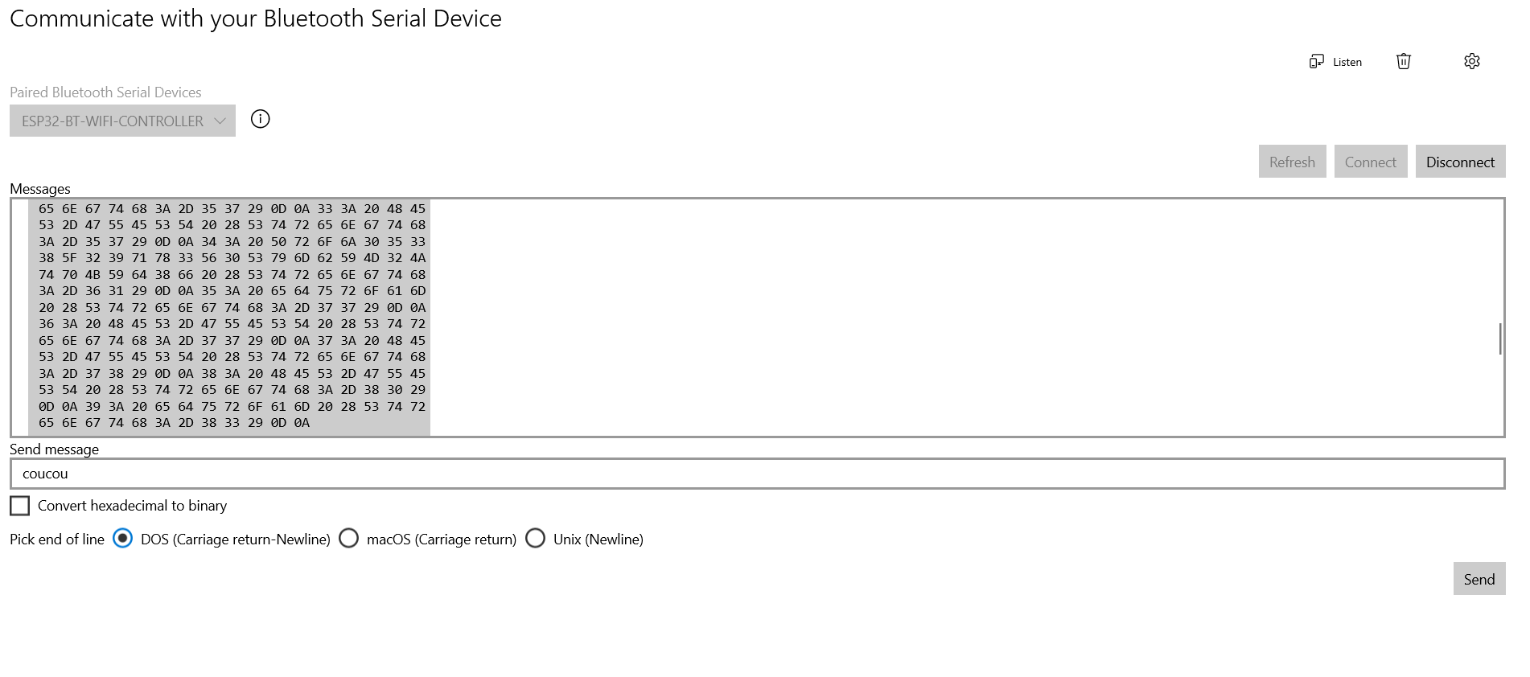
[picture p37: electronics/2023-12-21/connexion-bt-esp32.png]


## 2024-01-12

Mise a jour du user journey

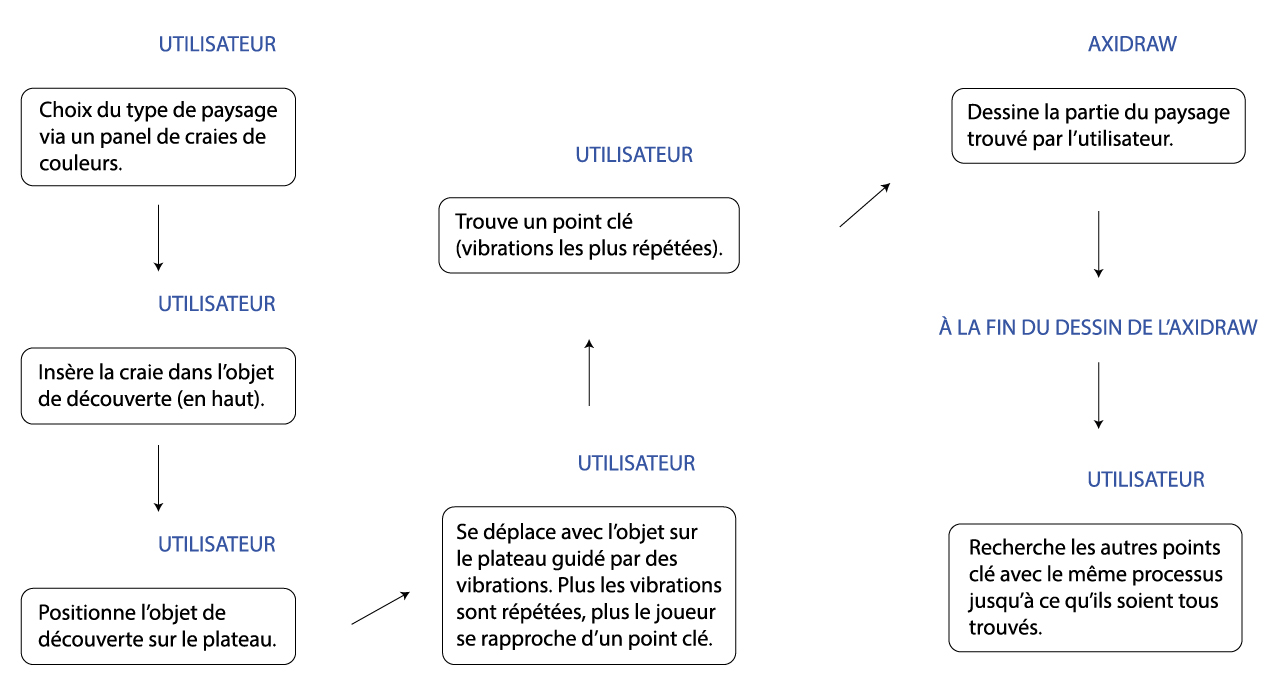
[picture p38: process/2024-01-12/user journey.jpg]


## 2024-01-10

Plan drawings des objets

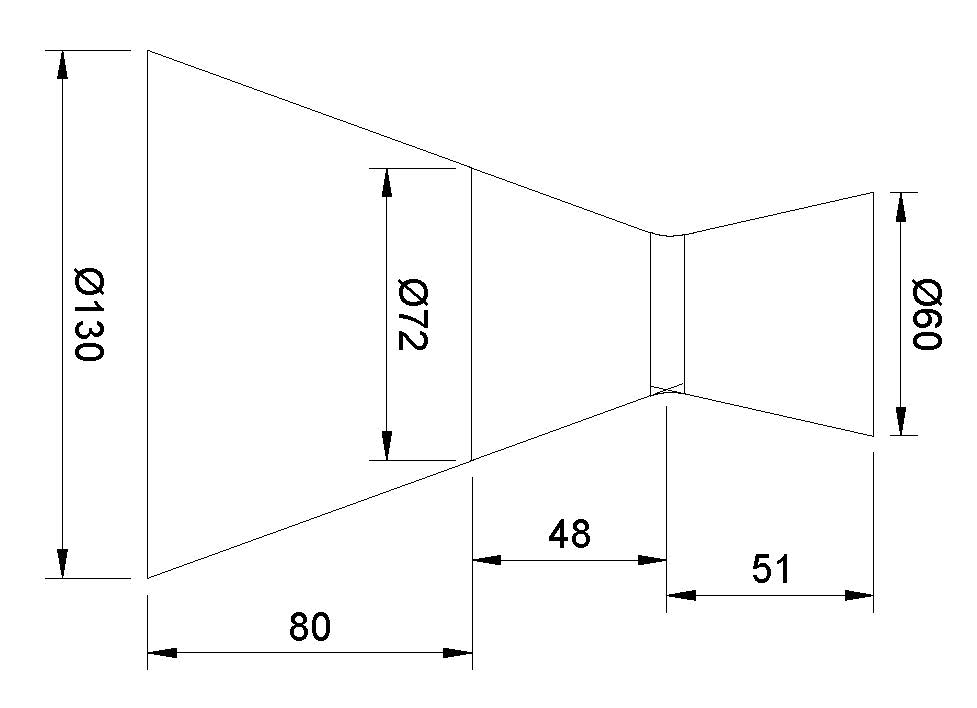
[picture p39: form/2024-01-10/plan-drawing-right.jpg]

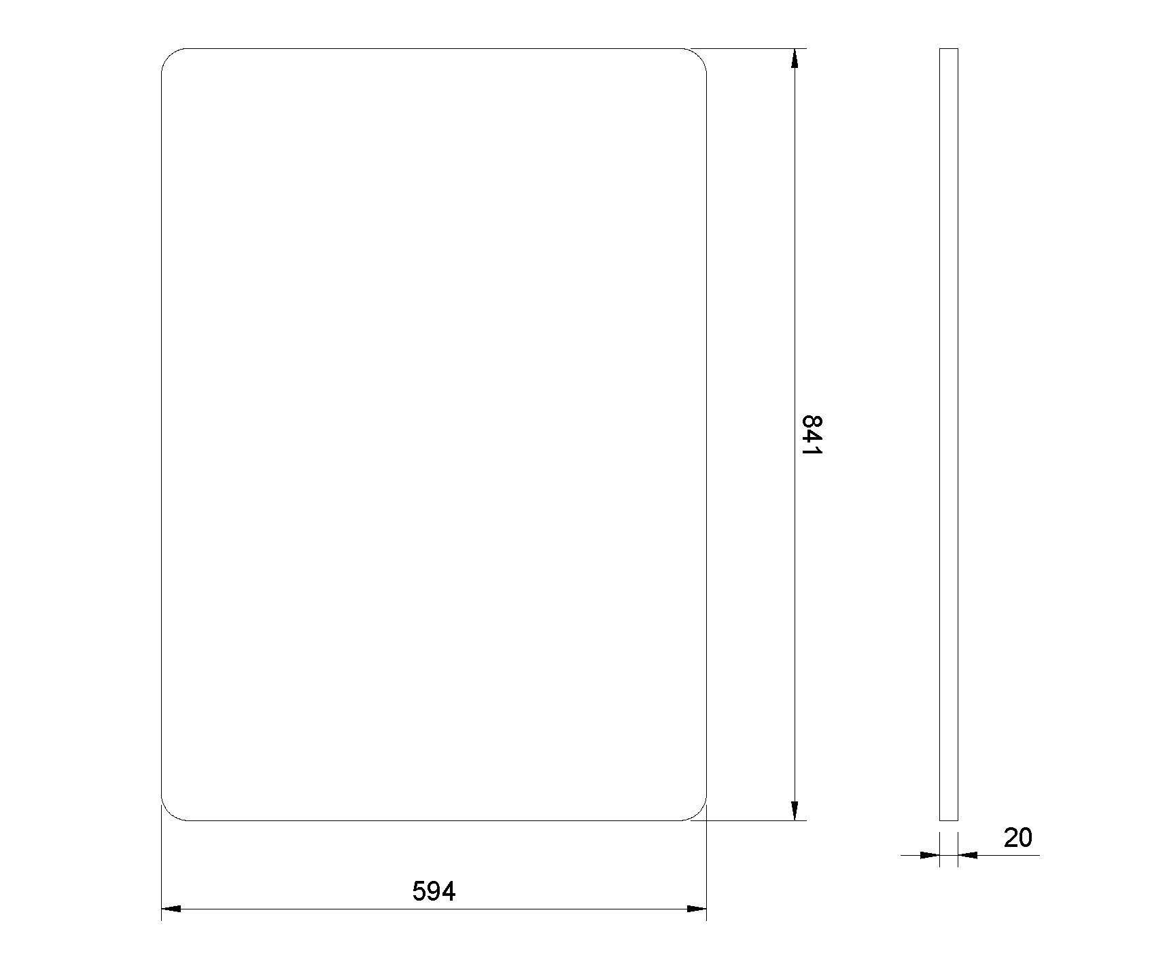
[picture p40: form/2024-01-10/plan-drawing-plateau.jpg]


## 2024-01-11

Rendus 3D pour la presentation de l'objet dans son aspect final :
sketch 1
sketch 1
sketch 1

## 2024-01-15

Schemas fritzing

sketch 1
sketch 1

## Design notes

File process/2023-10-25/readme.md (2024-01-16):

# Exercice prototypage papier
-> Exercice menant a faire des prototypage papier des interaction que l'on peut avoir avec un objet. Cartes tirées (dreamy, ballpoint, color filter, peltier, merge)

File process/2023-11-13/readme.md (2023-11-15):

# Defining an idendity

## Retours de Laure

* Revoir l'output : avoir un element physique (mieux), que digital (du type AR), plus se tourner vers le drawing machine,
* Redefinir l'utilisation des vibrations,
* Explorer, utiliser les outils de dessins,
* Donner des contraintes a l'IA dans le côté génératif,
* Experimenter (prototype papier) une forme assez large pour une prise avec les deux mains a la fois,
* Definir l'input (ce que definit/donne l'utilisateur)

## Pitch

Interagir avec un espace qu'on assemble mais qu'on ne connais pas, le découvrir et le dévoiler via des vibrations tout au long du voyage.

## Concept

L'utilisateur choisit les anneaux qu'il finit par assembler comme un "totem" sur l'objet (input), qui, en fonction des combinaisons choisies générer un paysage que l'utilisateur doit découvrir et dévoiler. Pour cela, il devra se balader avec l'objet sur un canva (feuille) et jouer avec les vibrations pour trouver les endroits intéressants. Une fois trouvé, il pourra attendre et contempler cette partie du paysage à la fois avec des vibrations qui simuleraient les textures, ainsi qu'avec le dessin qu'effectue l'objet. L'utilisateur peut continuer jusqu'à ce qu'il ne ressente plus de vibration sur tout le canva.

## User scenario

user journey of prototype 1

### Paper prototype & user testing

## Behavior of the object ?

*(A integrer dans les tests de prototype, a determiner)*

## What physical (or virtual 3d) objects are necessary to carry out the user scenario?

* Outils de dessins variés,
* Feuilles de papiers

## Target audience

### Who is my target audience and in which context shall my project be evolving?
revoir l'output de l'objet - manque la collaboration

-> explorer differents prototypes (laisser par terre a plusieurs + tracer le chemin et dessin autour)

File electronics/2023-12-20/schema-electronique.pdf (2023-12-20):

### Schéma electronique/electrique

ESP32
3.7v

grnd

vbat 3.3v

VIBR

IN

s

19

18

5

23

15 OUT

IN
miso

mosi

SCK

cs
IN

OUT

OUT

RFID

IN

IN

OUT

OUT

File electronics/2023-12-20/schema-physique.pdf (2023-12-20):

### Schéma physique

Pion | Axidraw Connection filaire Connection bluetooth

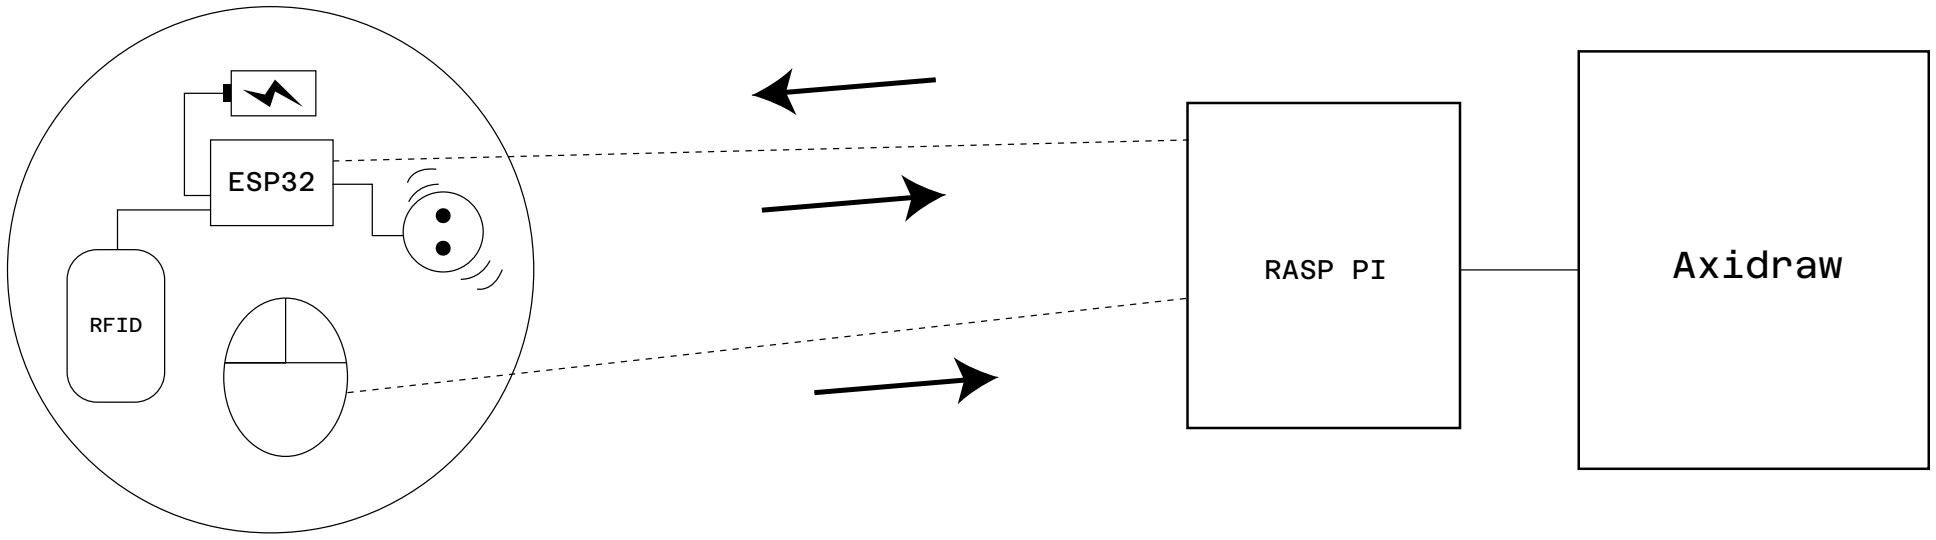
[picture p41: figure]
Axidraw; ESP32; RFID; RASP PI

Souris bluetooth
RFID Capteur
ESP32
Vibreurs
Batterie

Raspberry Pi
Axidraw

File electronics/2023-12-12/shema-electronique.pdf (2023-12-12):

Schéma electronique/electrique

ESP32
3.7v

grnd

VIBR

IN

IN

RFID

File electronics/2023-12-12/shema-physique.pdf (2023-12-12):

### Schéma physique

Pion | Axidraw Connection filaire Connection bluetooth

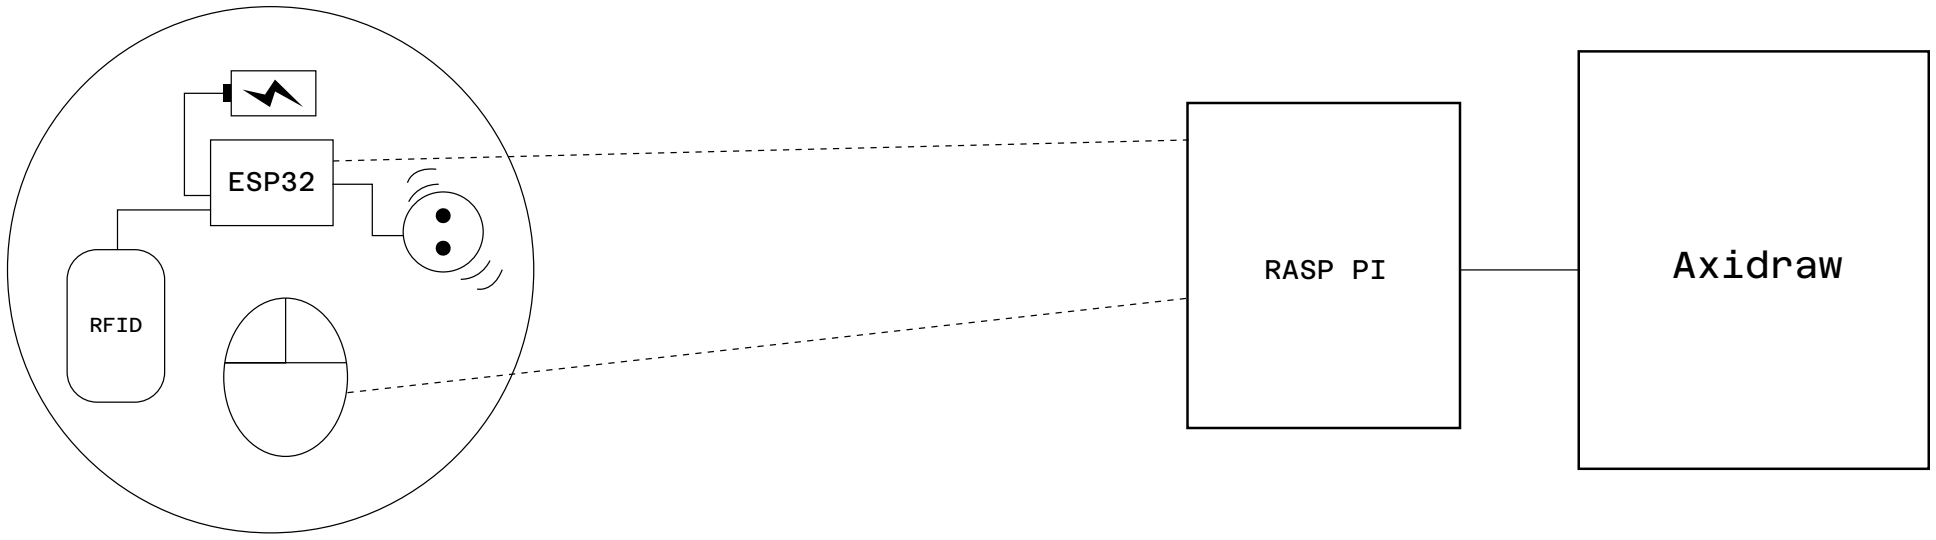
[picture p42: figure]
Axidraw; ESP32; RFID; RASP PI

Souris bluetooth
RFID Capteur
ESP32
Vibreurs
Batterie

Raspberry Pi
Axidraw

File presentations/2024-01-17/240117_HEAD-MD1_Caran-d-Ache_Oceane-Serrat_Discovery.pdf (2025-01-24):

Océane Serrat
Discovery
Master Media Design 1 | 17-01-2024
Caran d’Ache
Future of Drawing

# Discovery

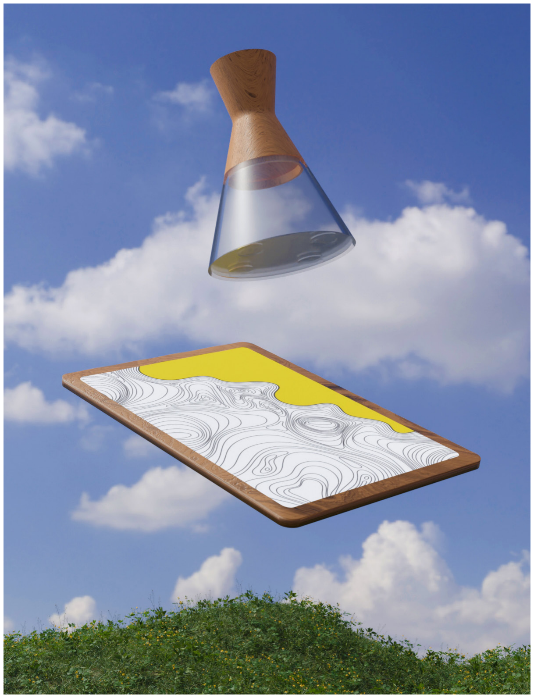
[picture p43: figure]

# Project Description

Discovery est un jeu qui donne un nouveau regard sur la pratique du dessin. Guidé par le sens du toucher, il explore la collaboration entre l’objet et le joueur dans un processus de création.

L’objet invite le joueur à interagir avec un espace qu’il choisit via une craie, révélant progressivement un paysage dessiné à travers des vibrations tout au long de l’expérience.

Discovery est idéal pour expérimenter, dessiner de façon intuitive, ou tout simplement dans un moment contemplatif.

Le jeu permet de rendre accessible le dessin à toute personne curieuse, motivée, ou démotivée dans l’apprentissage de cette pratique, ou simplement celles qui ne pratiquent pas d’art créatif en général.

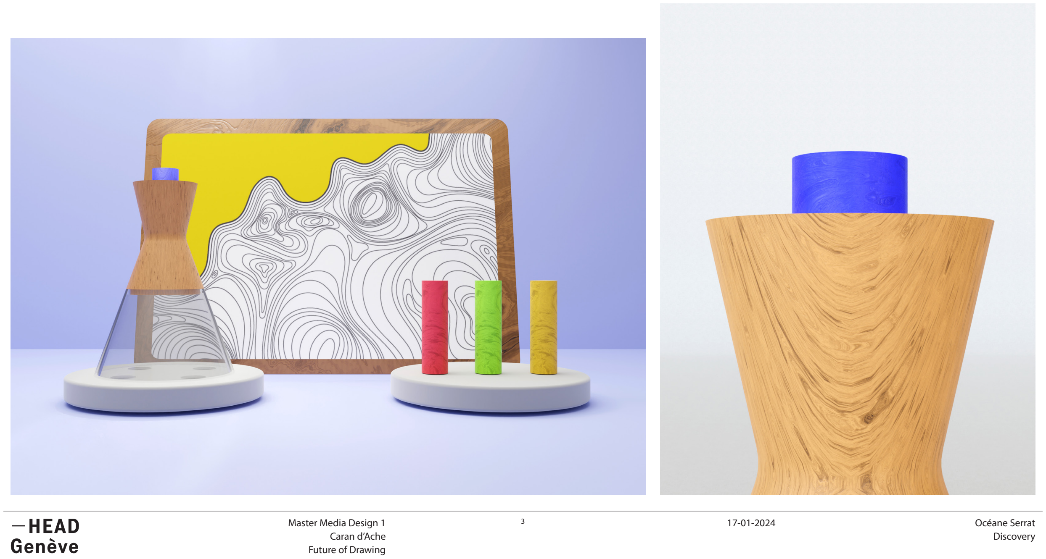
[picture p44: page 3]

# User Journey

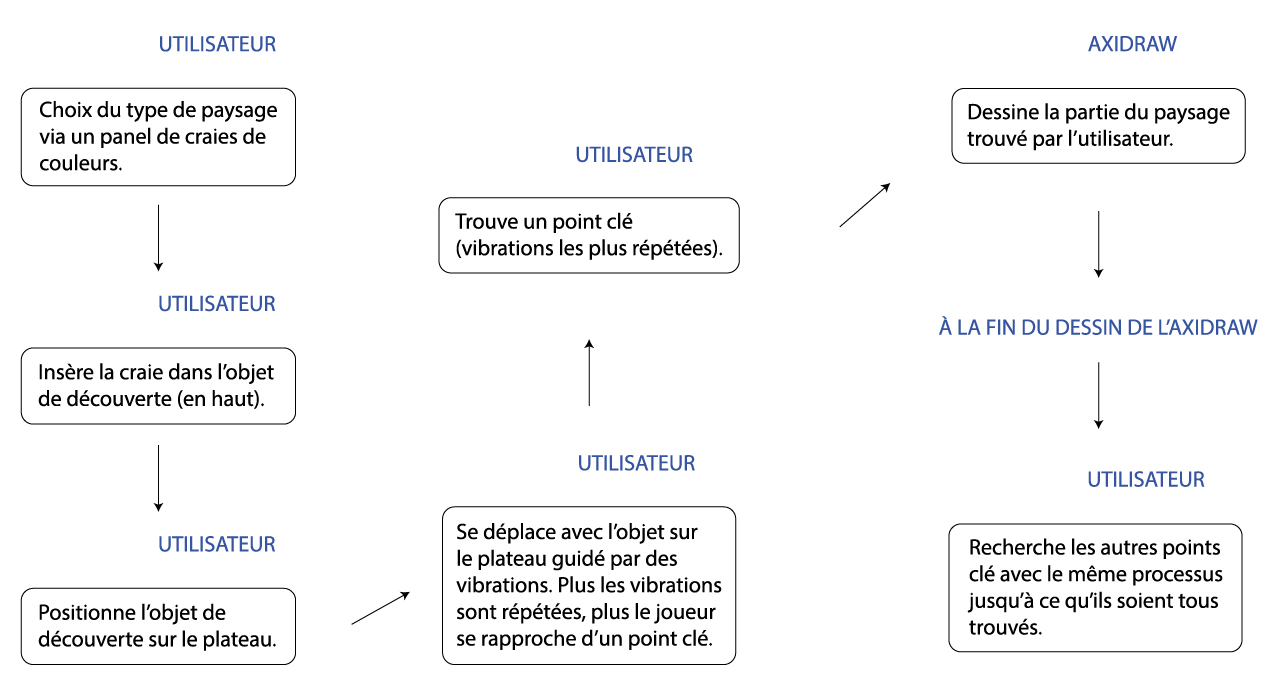
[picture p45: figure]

# Field observations

1. Expérimentations : moins de frustrations sur la façon de dessiner avec la première expérience, utilisation du toucher pour dessiner, mouvements plus libérés, activité fun. L’idée de faire une expérience ou on découverte au fur et à mesure le dessin qu’on a construit viens de ces expérimentations.
2. Interviews sur les peurs autour de la pratique du dessin :
- Pas de dessin réussi ou non : doit plaire d’abord à soimême, pas de catégories spécifiques, dessiner au feeling.
- Frustrations, déception, perfectionnisme, blocage sur les détails.

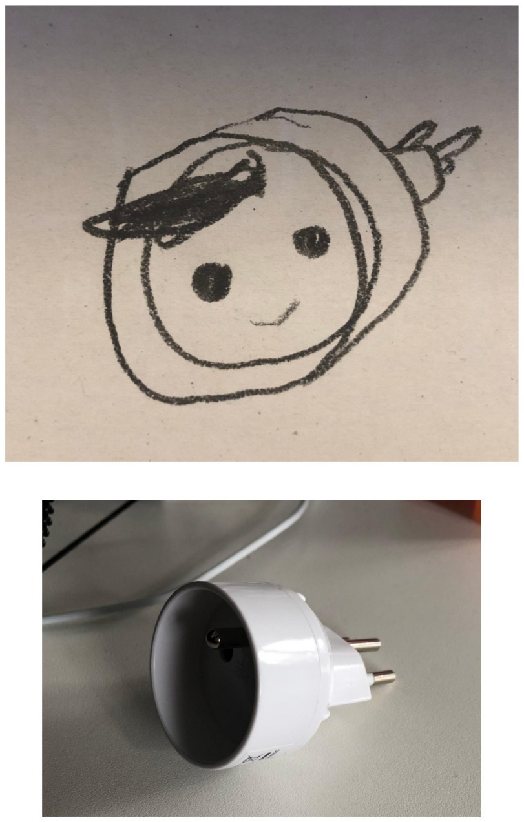
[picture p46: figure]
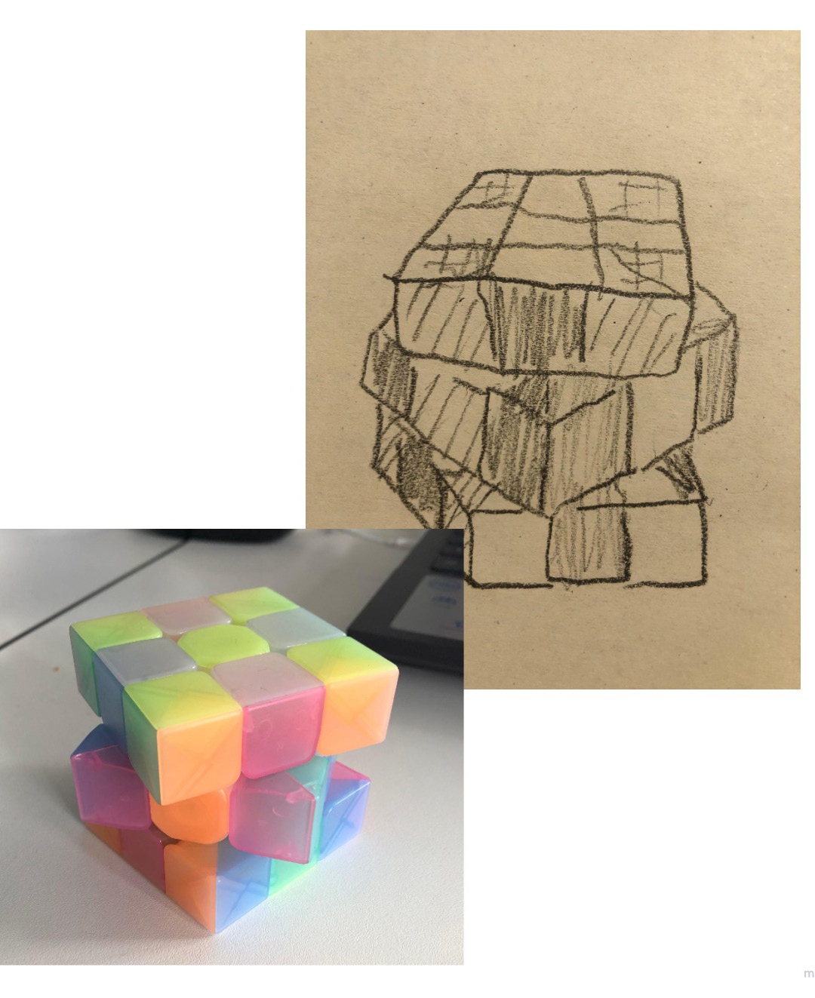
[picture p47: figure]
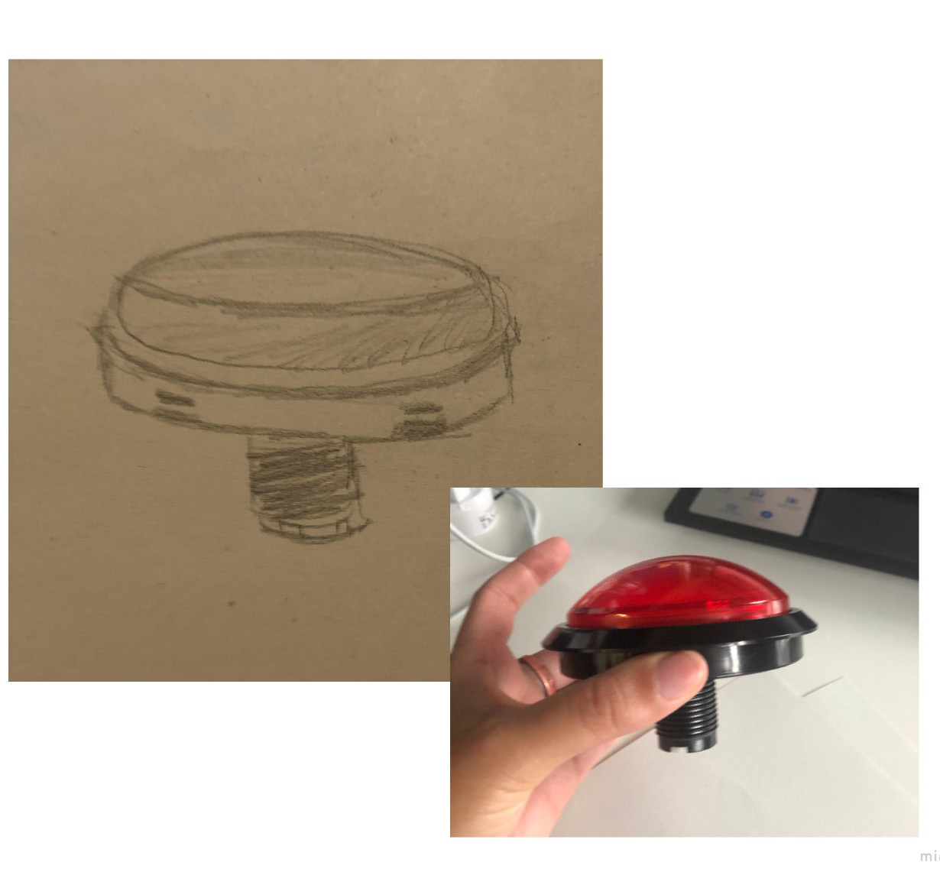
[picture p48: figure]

# Visual and Material Moodboard

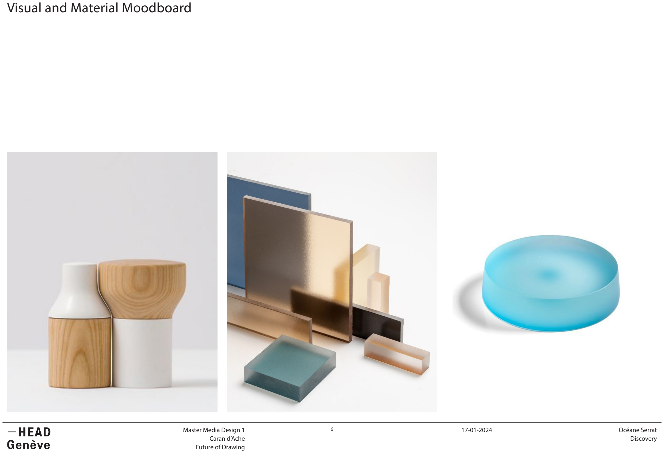
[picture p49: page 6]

# Shape research

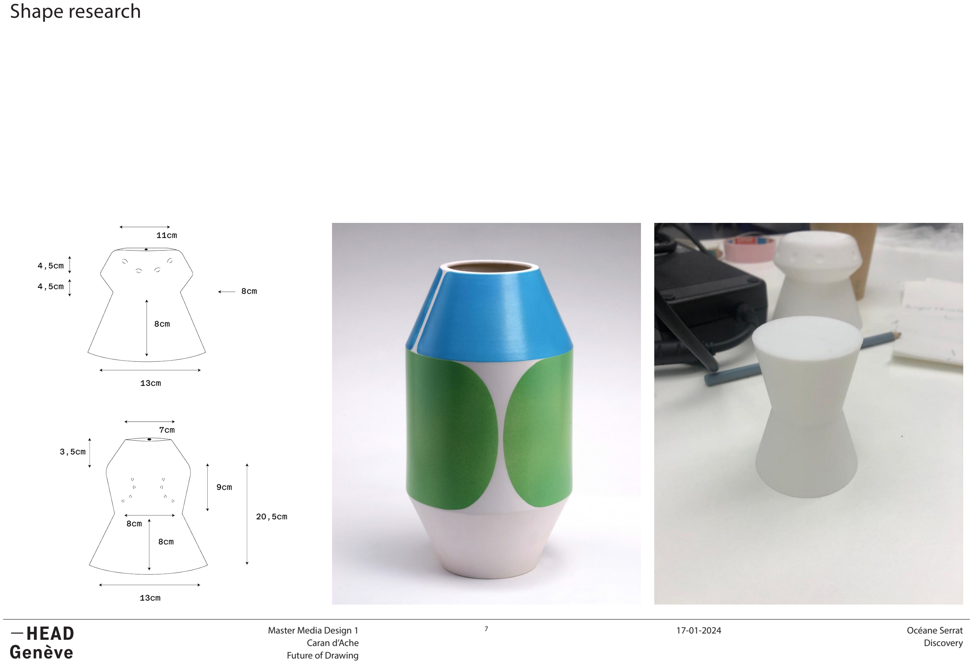
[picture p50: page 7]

# Paper Prototypes

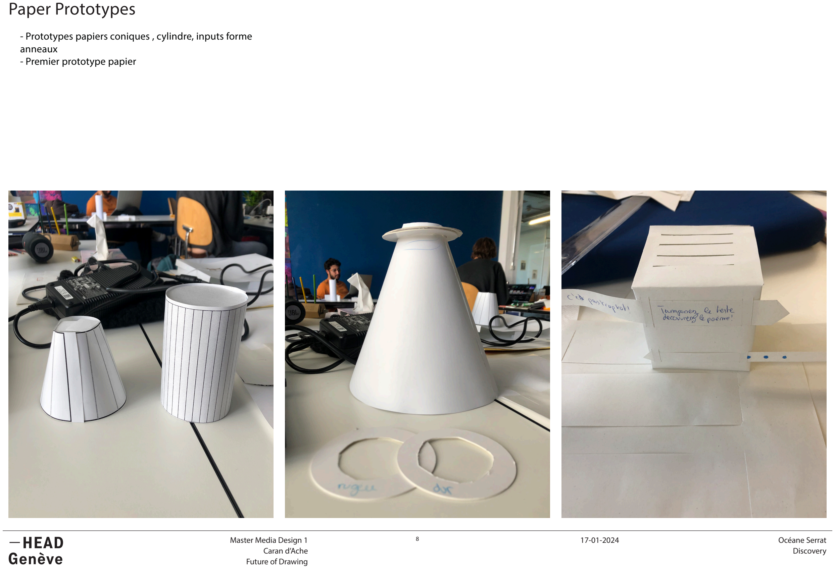
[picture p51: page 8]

- Prototypes papiers coniques , cylindre, inputs forme anneaux
- Premier prototype papier

# User Tests

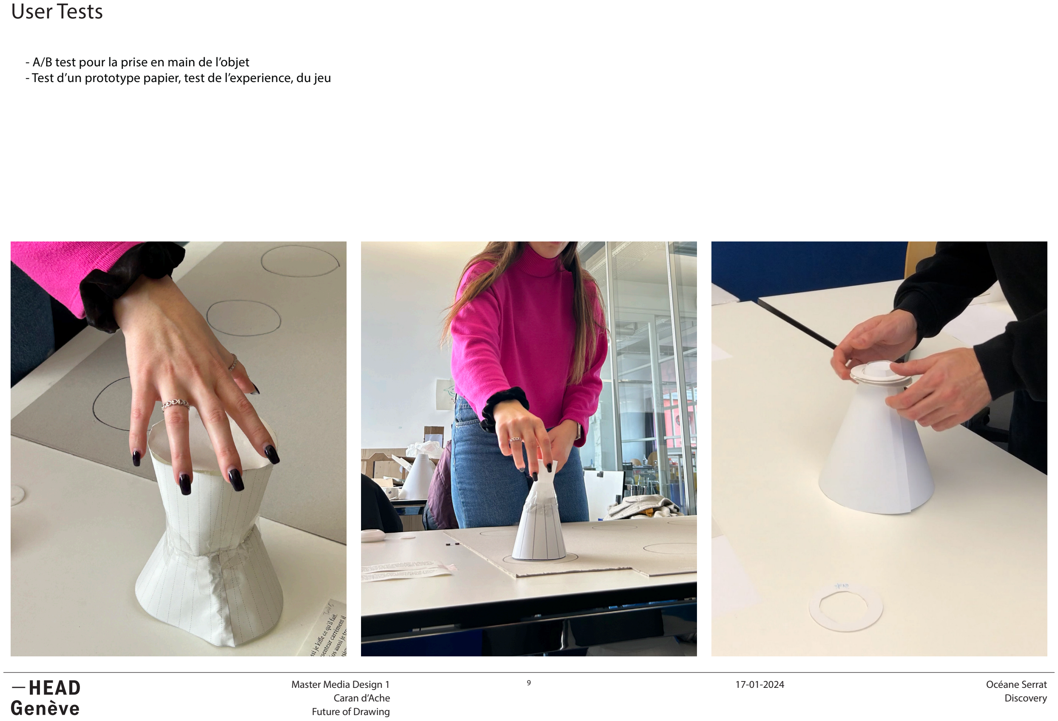
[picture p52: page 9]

- A/B test pour la prise en main de l’objet
- Test d’un prototype papier, test de l’experience, du jeu

# Electronics

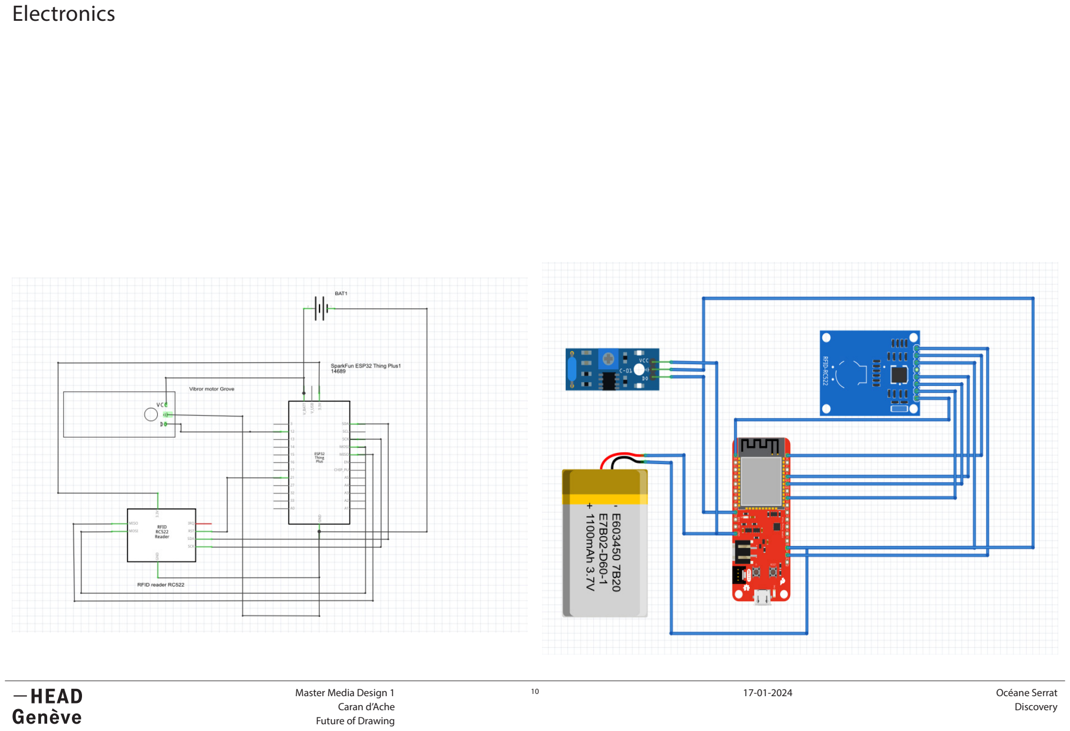
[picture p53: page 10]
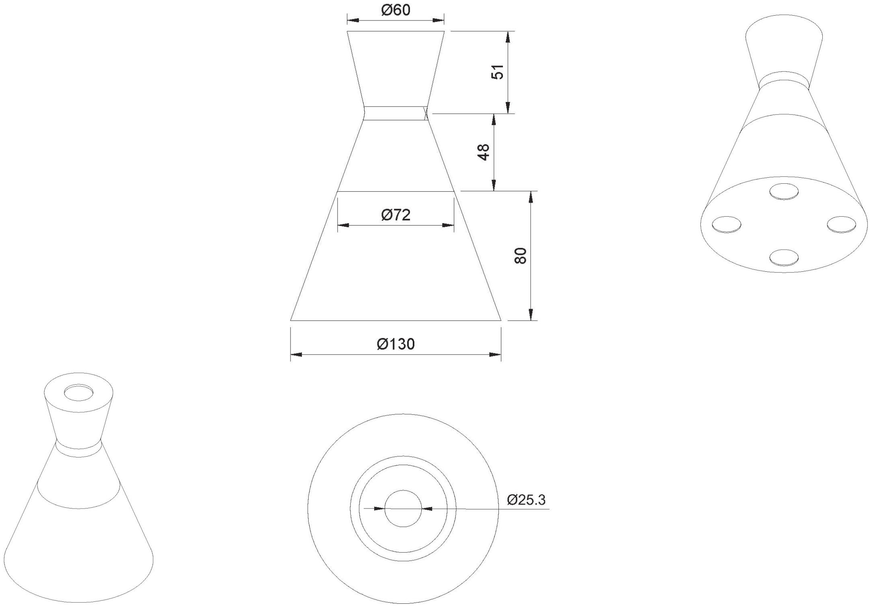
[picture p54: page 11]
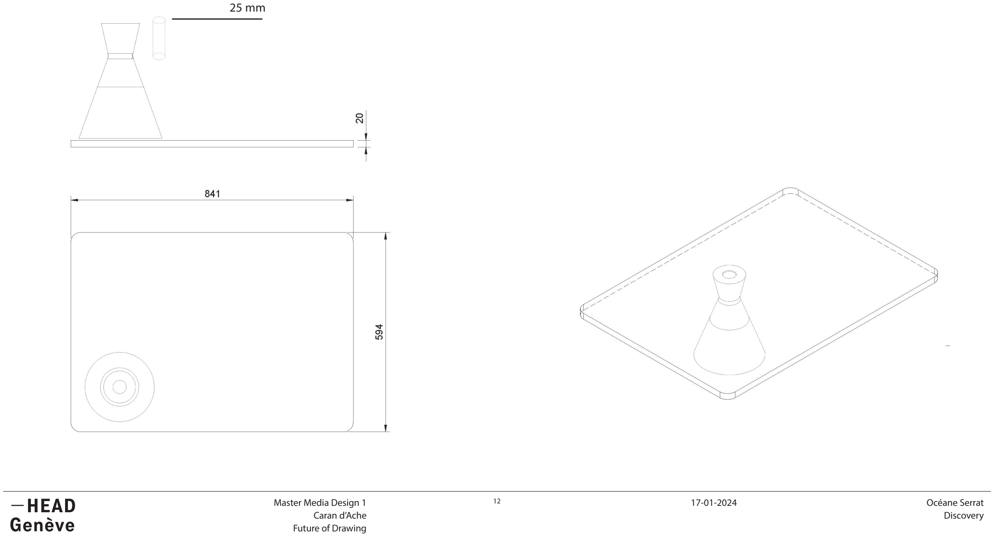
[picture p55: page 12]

25 mm

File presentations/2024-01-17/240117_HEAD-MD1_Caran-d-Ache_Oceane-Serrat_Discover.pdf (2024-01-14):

Océane Serrat
Discover
Master Media Design 1 | 17-01-2024
Caran d’Ache
Future of Drawing

# Discover

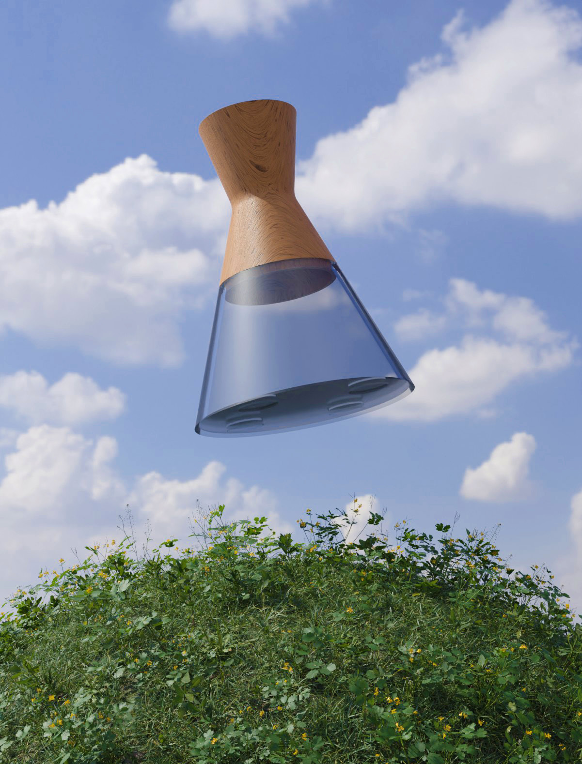
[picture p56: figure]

# Project Description

Discover est un jeu qui donne un nouveau regard sur la pratique du dessin. Guidé par le sens du toucher, il explore la collaboration entre l’objet et le joueur dans un processus de création.
L’objet invite le joueur à interagir avec un espace qu’il choisit via une craie, révélant progressivement un paysage dessiné à travers des vibrations tout au long de l’expérience.
Discover est idéal pour expérimenter, dessiner de façon intuitive, ou tout simplement dans un moment contemplatif.
Le jeu permet de rendre accessible le dessin à toute personne curieuse, motivée, ou démotivée dans l’apprentissage de cette pratique, ou simplement celles qui ne pratiquent pas d’art créatif en général.

Additional project visuals Additional project visuals

# User Journey

User journey showing the key interaction. Think from start to finish, show the whole experience.
Beetroot water spinach okra water chestnut ricebean pea catsear courgette summer purslane. Water spinach arugula pea tatsoi aubergine spring onion bush tomato kale radicchio turnip chicory salsify pea sprouts fava bean. Dandelion zucchini burdock yarrow chickpea dandelion sorrel courgette turnip greens tigernut soybean radish artichoke wattle seed endive groundnut broccoli arugula.

Expressed through reference images, sketches,
diagrammes or...

# Field observations

What are you basing your project on? Don’t just show other artists references, we want to see you own field research. Beetroot water spinach okra water chestnut ricebean pea catsear courgette summer purslane. Water spinach arugula pea tatsoi aubergine spring onion bush tomato kale radicchio turnip chicory salsify pea sprouts fava bean. Dandelion zucchini burdock yarrow chickpea dandelion sorrel courgette turnip greens tigernut soybean radish artichoke wattle seed endive groundnut broccoli arugula.

# Visual and Material Moodboard

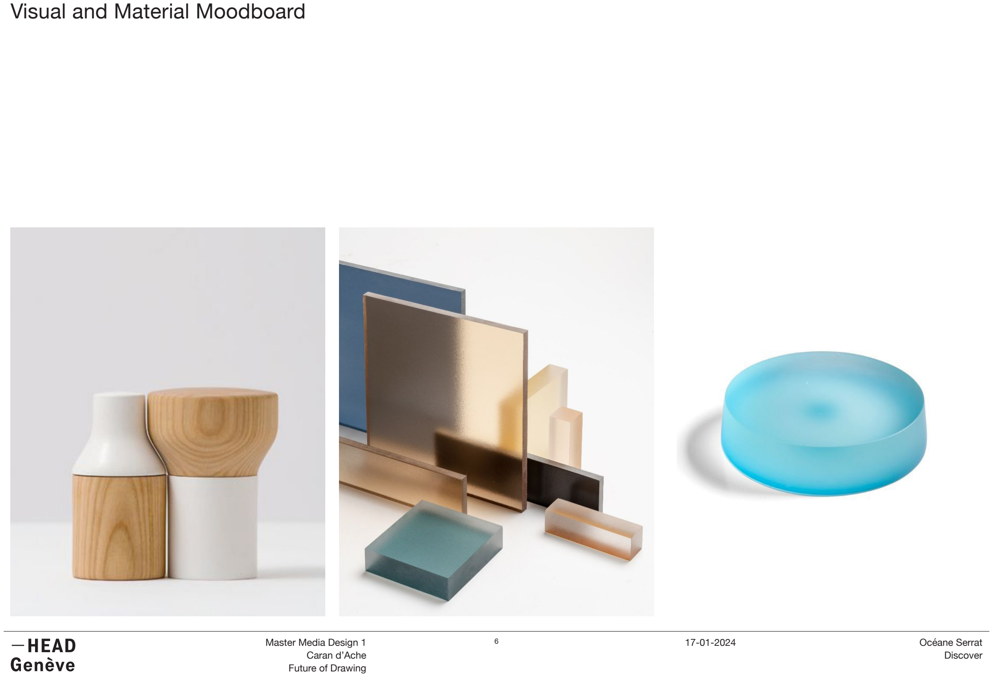
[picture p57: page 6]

# Shape research

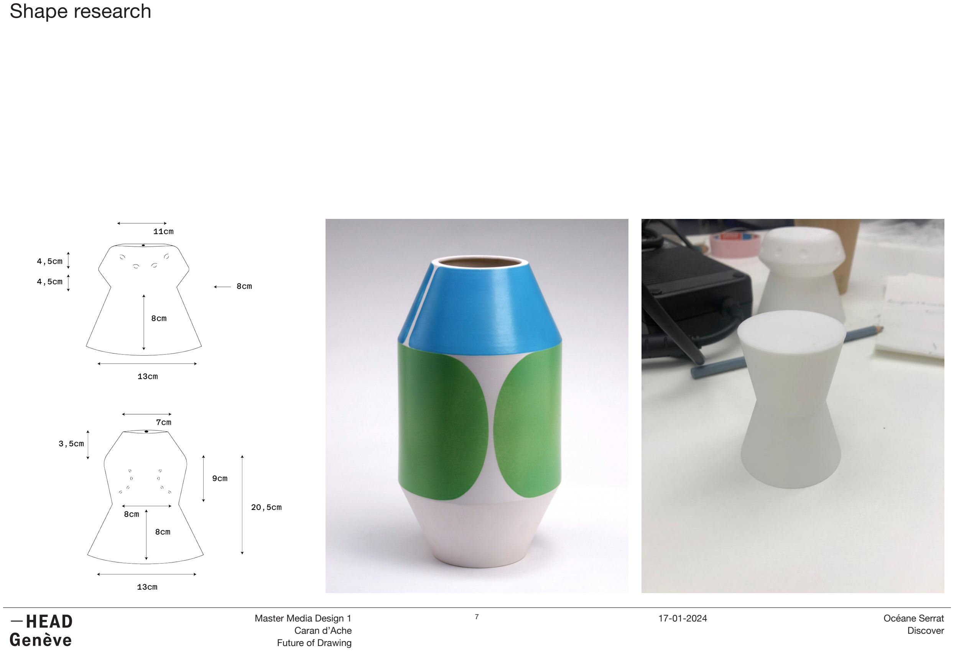
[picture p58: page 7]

# Paper Prototypes

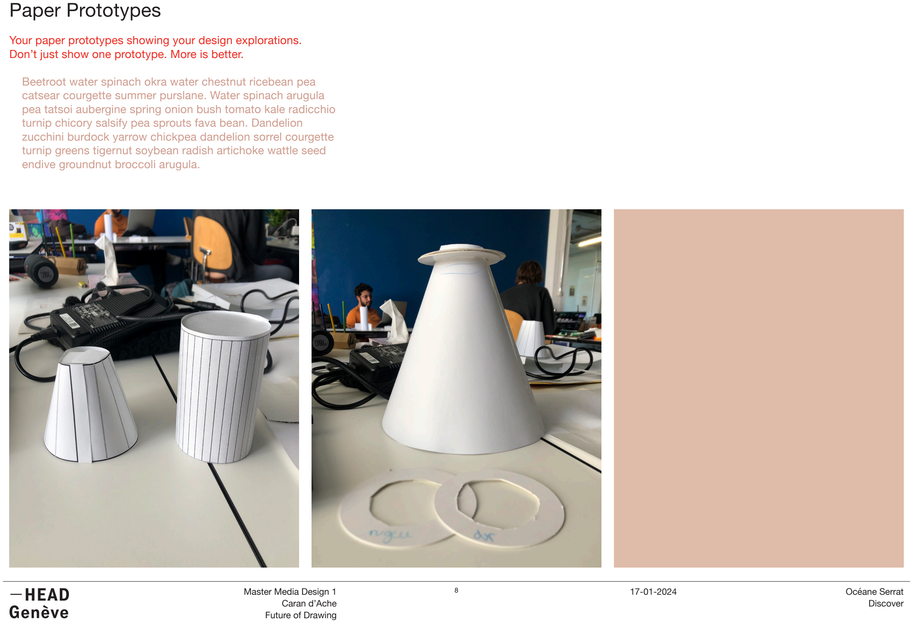
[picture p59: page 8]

Your paper prototypes showing your design explorations. Don’t just show one prototype. More is better.
Beetroot water spinach okra water chestnut ricebean pea catsear courgette summer purslane. Water spinach arugula pea tatsoi aubergine spring onion bush tomato kale radicchio turnip chicory salsify pea sprouts fava bean. Dandelion zucchini burdock yarrow chickpea dandelion sorrel courgette turnip greens tigernut soybean radish artichoke wattle seed endive groundnut broccoli arugula.

# User Tests

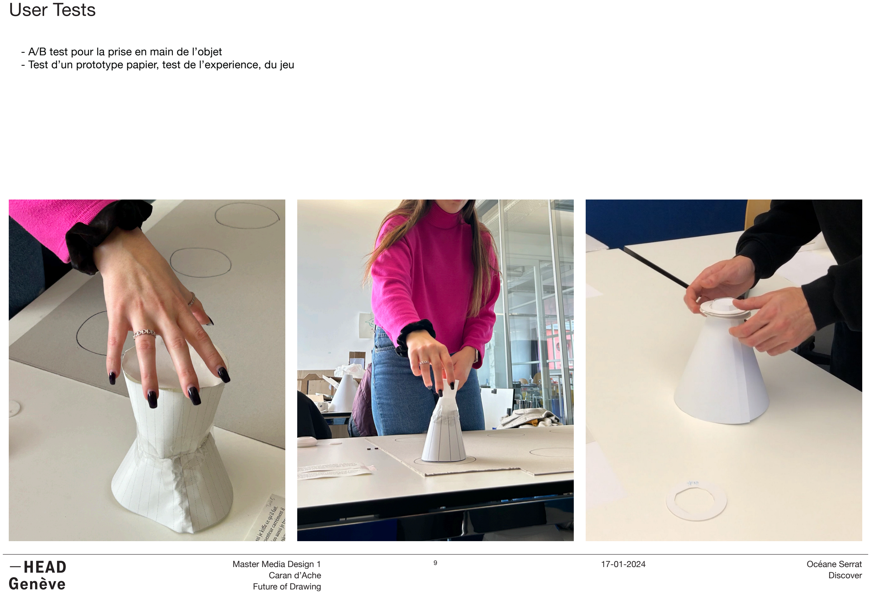
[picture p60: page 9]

- A/B test pour la prise en main de l’objet
- Test d’un prototype papier, test de l’experience, du jeu

# Electronics

Electronic schematic | Fritzing schematic (optional)

# Plan Drawings

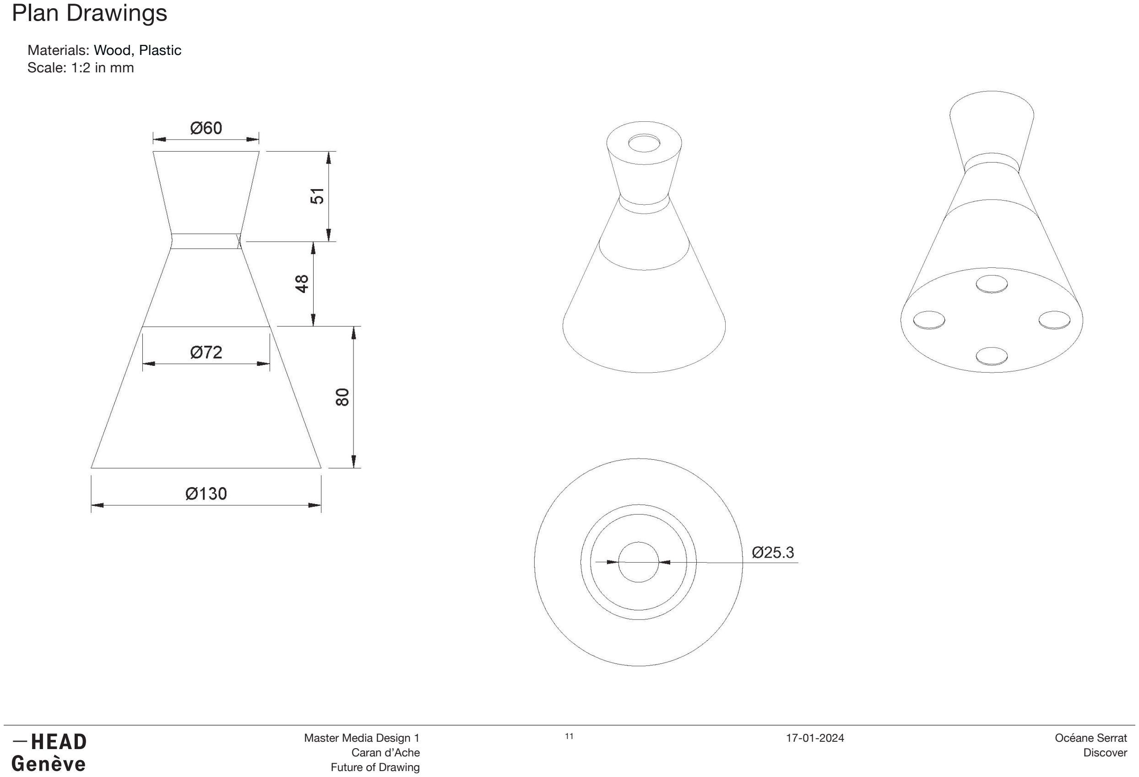
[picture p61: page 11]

Materials: Wood, Plastic
Scale: 1:2 in mm

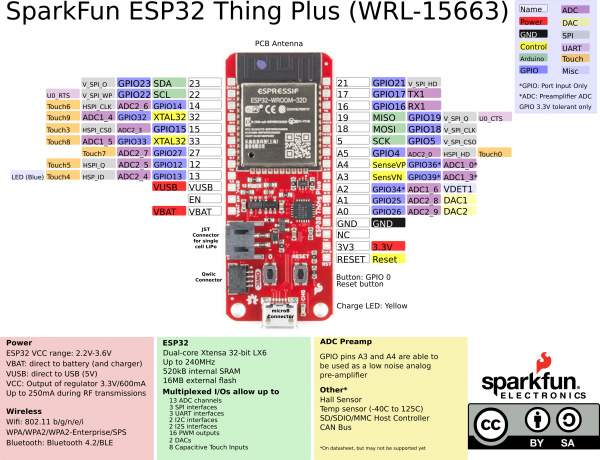
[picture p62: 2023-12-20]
electronics/2023-12-20/ESP32ThingPlusV20_GraphicalDatasheet.jpg

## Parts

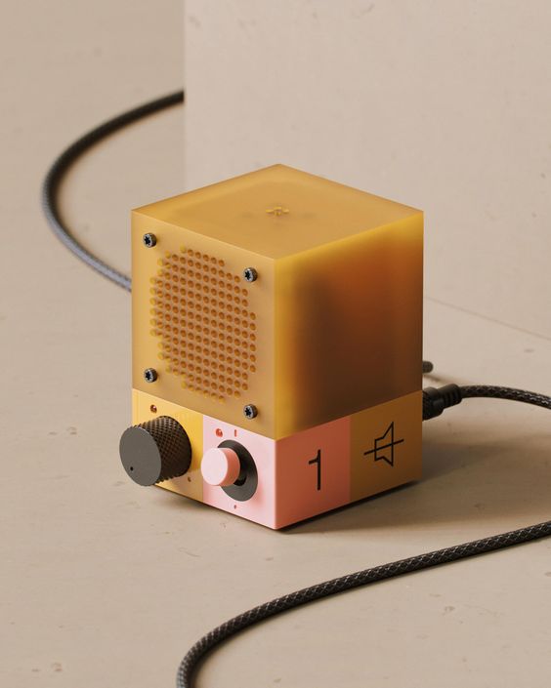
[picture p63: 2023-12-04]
process/2023-12-04/material-2.jpg

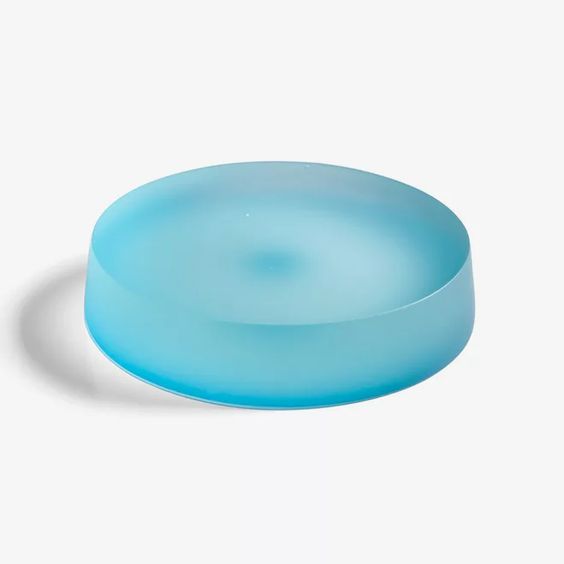
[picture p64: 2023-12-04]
process/2023-12-04/material-1.jpg

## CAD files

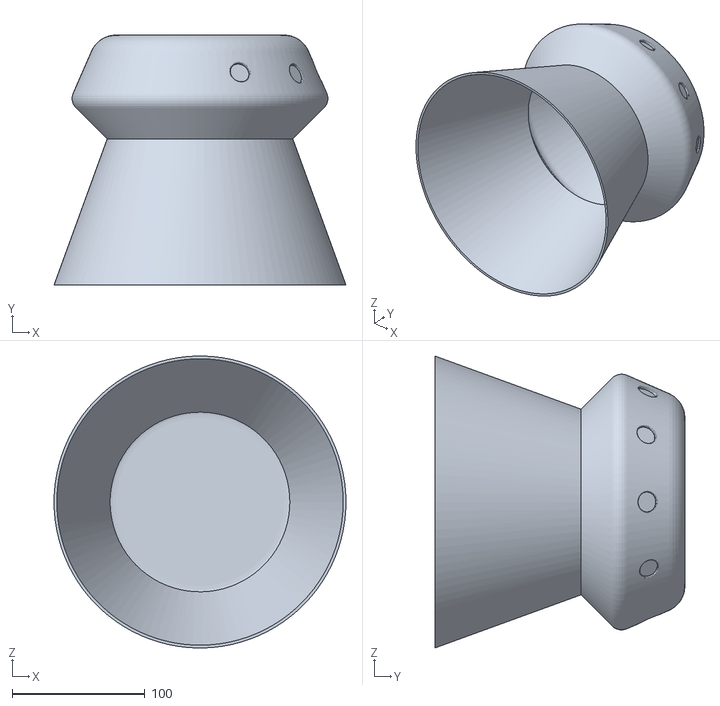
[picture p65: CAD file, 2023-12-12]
form/2023-12-11/forme1 v4.stl
220.0 x 188.3 x 219.9

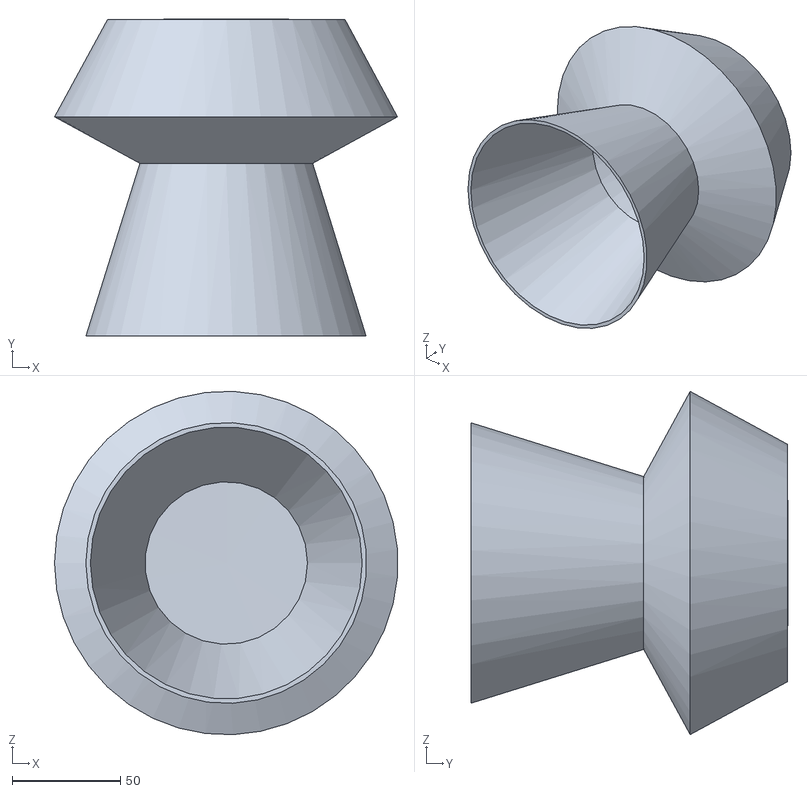
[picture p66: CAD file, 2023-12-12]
form/2023-12-12/fichiers-depliant/forme1.obj
158.8 x 146.9 x 158.9

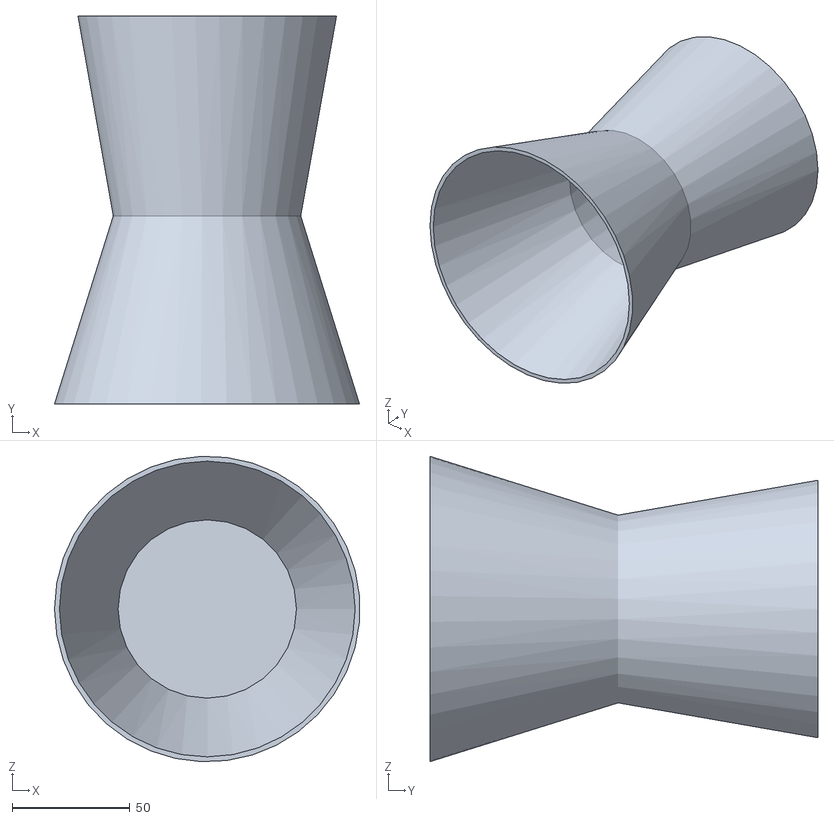
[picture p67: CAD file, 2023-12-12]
form/2023-12-12/forme2 v3.obj
129.8 x 165.0 x 129.9

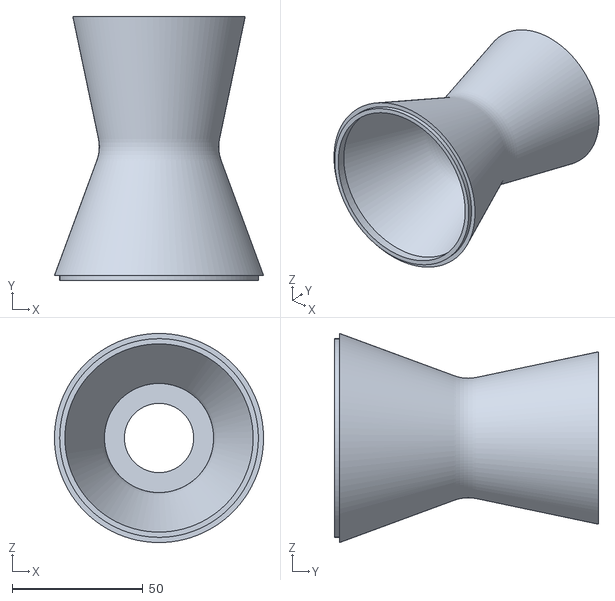
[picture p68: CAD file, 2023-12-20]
form/2023-12-20/test-print.stl
80.0 x 101.0 x 80.0

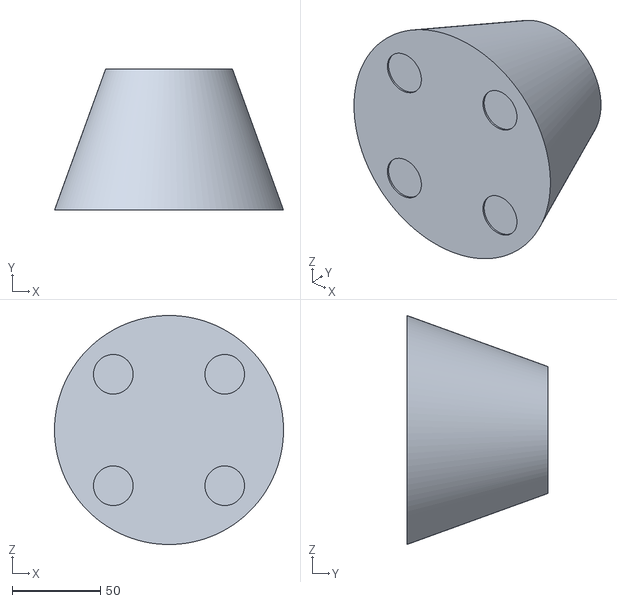
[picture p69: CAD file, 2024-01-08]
form/2024-01-06/partie-basse-pion.stl
130.0 x 80.0 x 130.0

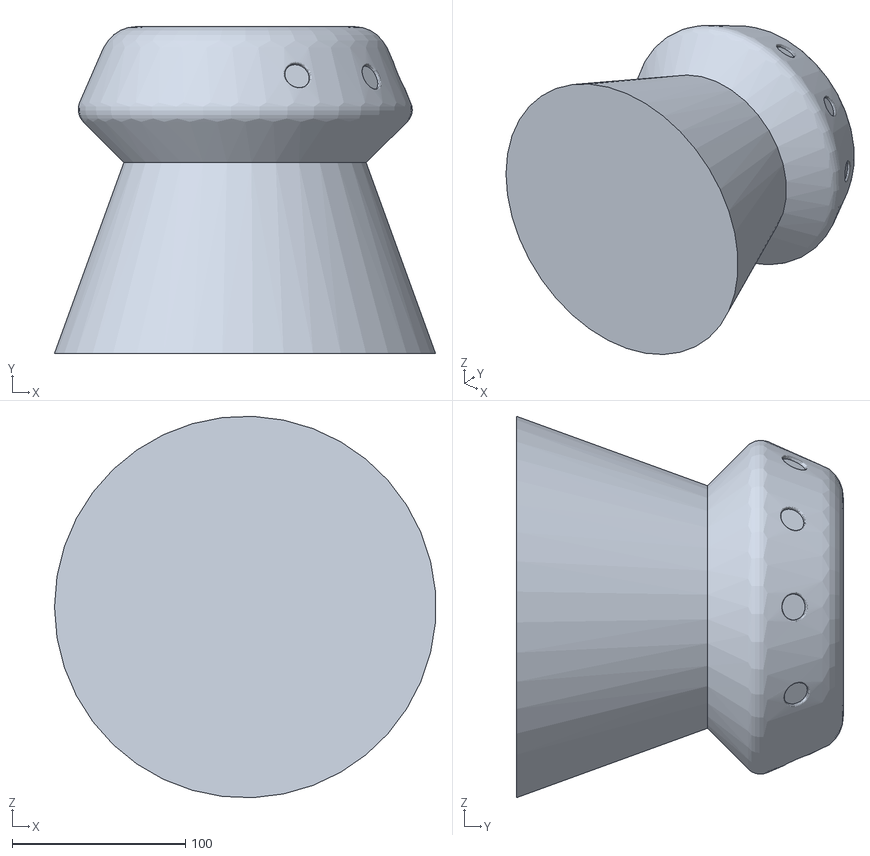
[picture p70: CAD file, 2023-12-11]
form/2023-12-11/forme1.obj
219.6 x 188.3 x 219.8

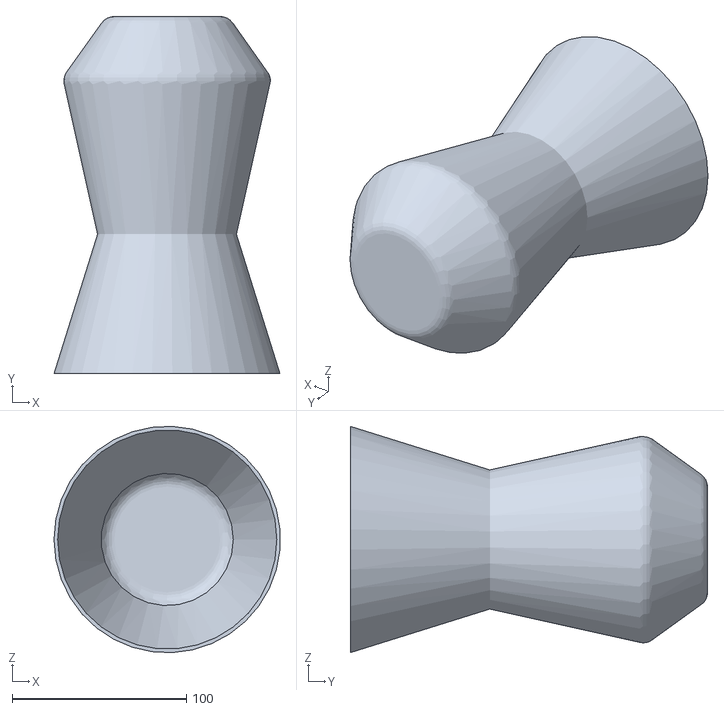
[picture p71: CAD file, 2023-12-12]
form/2023-12-12/fichiers-depliant/forme4.obj
129.7 x 205.0 x 129.9

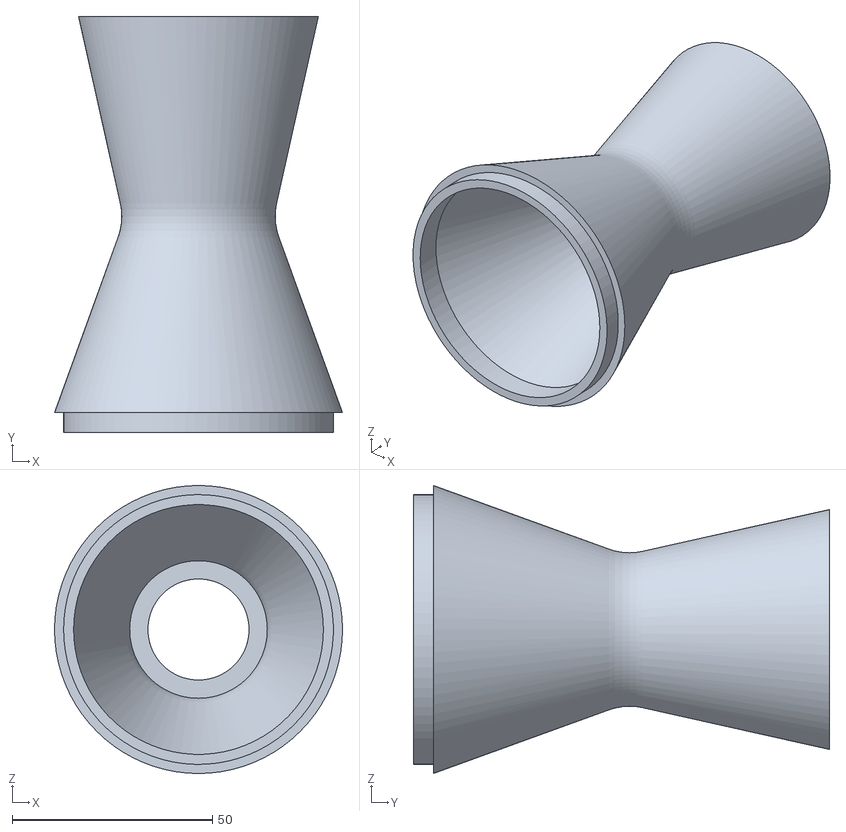
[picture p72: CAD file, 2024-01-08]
form/2024-01-06/partie-haute-pion.stl
72.0 x 104.0 x 72.0

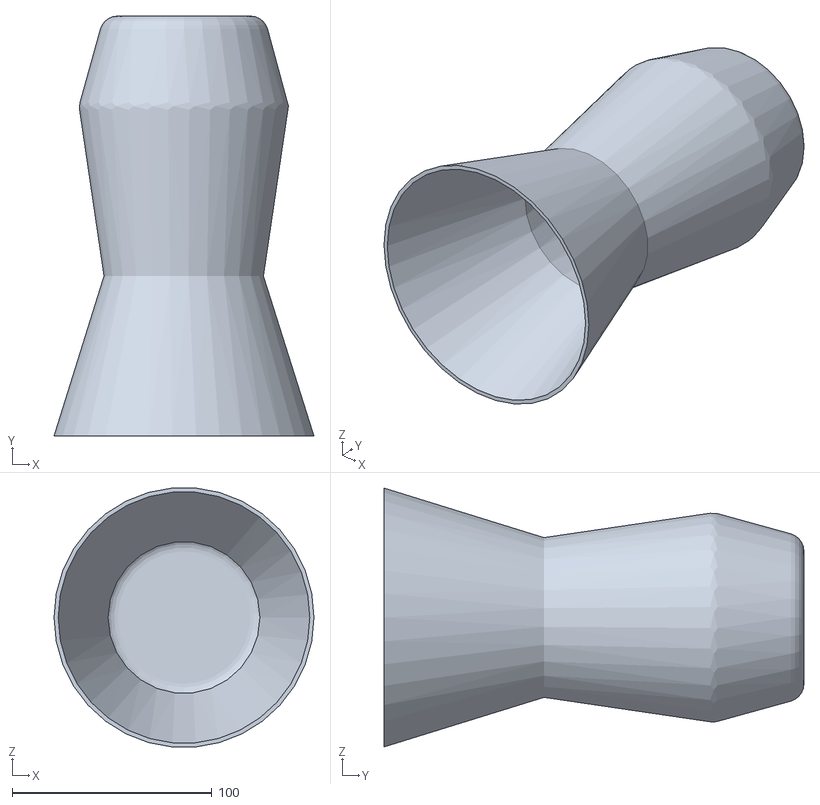
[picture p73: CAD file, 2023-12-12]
form/2023-12-12/fichiers-depliant/forme3.obj
130.0 x 210.0 x 129.4

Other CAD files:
form/2023-12-12/fichiers-depliant/forme2.obj
form/2023-11-15/deplie-proto-papier.3dm
form/2023-12-05/sketch-form.blend
form/2023-12-11/forme1.f3d
form/2023-12-12/composant taille + base taille v1.f3d
form/2023-12-12/forme1 protopapier v1.f3d
form/2023-12-12/forme2 v1.f3d
form/2023-12-12/forme3proto v3.f3d
form/2023-12-12/forme4proto v2.f3d
form/2023-12-19/forme-maj-2023-12-19-c-ache v3.f3d
form/2023-12-21/forme-maj-2023-12-19-c-ache-bois v10.f3d
form/2023-12-21/forme-maj-2023-12-19-c-ache-impression-3d v2.f3d
form/2023-12-21/plateau-jeu-bois-c-ache v2.f3d
form/2024-01-11/assets/materials/boucle_fabric_504cd8b1-7b4f-446f-a7d4-8ddd79d13e87/boucle_fabric_43bba55f-74ad-4578-932d-5631b8d9e1b3.blend
form/2024-01-11/assets/materials/furniture_wood_a5ef688f-ef81-4dd6-8001-e7d91e778910/furniture_wood_ad6a0617-35d7-4a5d-bb2d-331be68830e6.blend
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

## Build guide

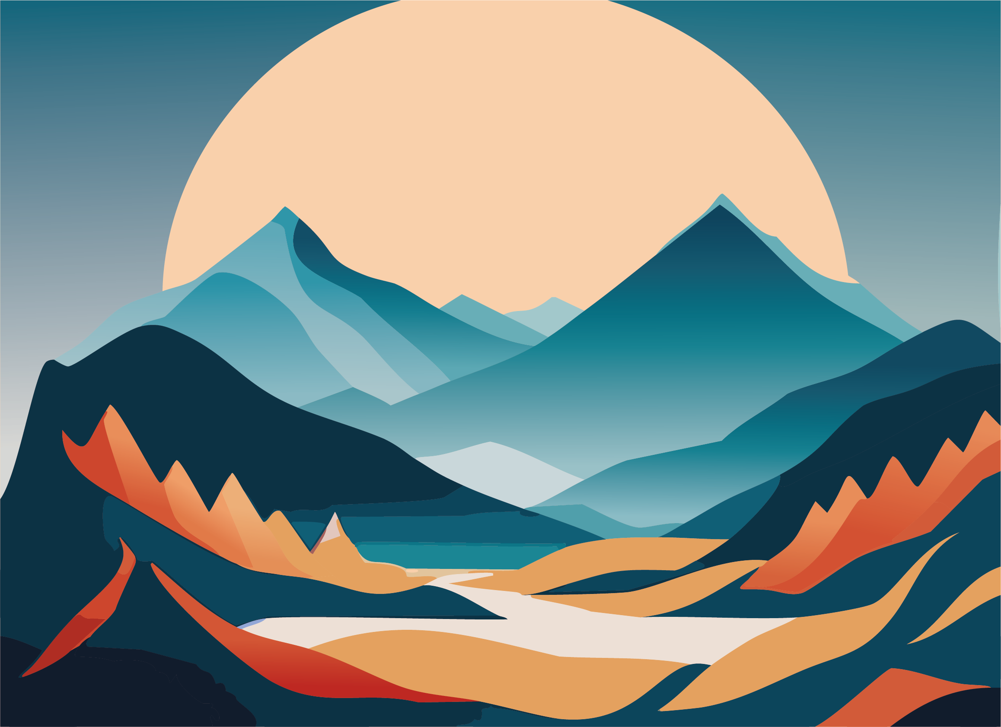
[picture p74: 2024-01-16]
process/2024-01-16/montagne/3.png

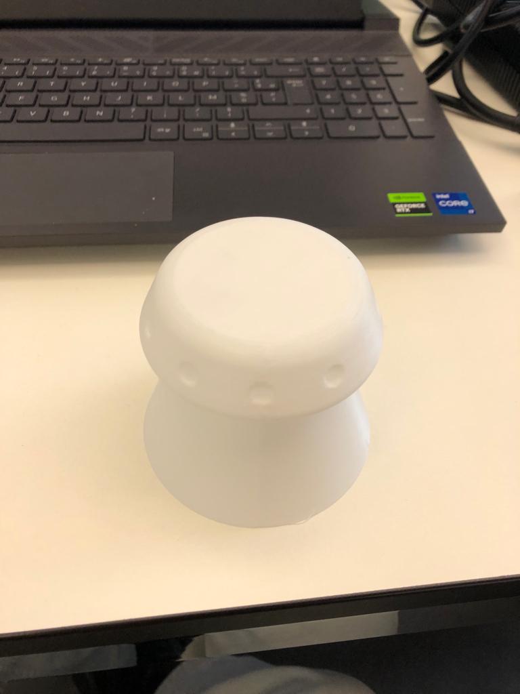
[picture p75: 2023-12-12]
form/2023-12-12/print3d-forme1v2.jpg

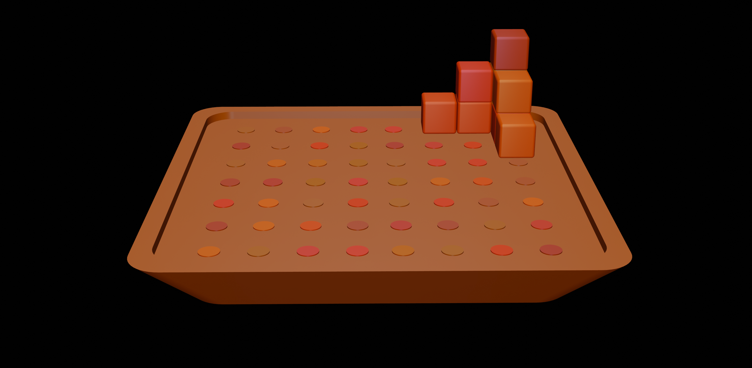
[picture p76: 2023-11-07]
process/2023-11-07/plateau-interactif-construction.png

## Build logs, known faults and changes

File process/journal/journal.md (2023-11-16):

# 2023-11-16

## Présentation milieu de projet Caran d'Ache

* Rassurée sur les possibilité d'évolution du projet,
* Frustration car pas 100% convaincu par plusieurs éléments, notemment : l'output, voir comment mieux intégrer la collaboration entre l'ia et l'objet
* Impression qu'il manque quelque chose
* Beaucoup de questionnements autour de est-ce que ça fonctionne vraiment/est-ce que c'est cohérent avec les recherches
* Quelques retours qui m'ont un peu perdue

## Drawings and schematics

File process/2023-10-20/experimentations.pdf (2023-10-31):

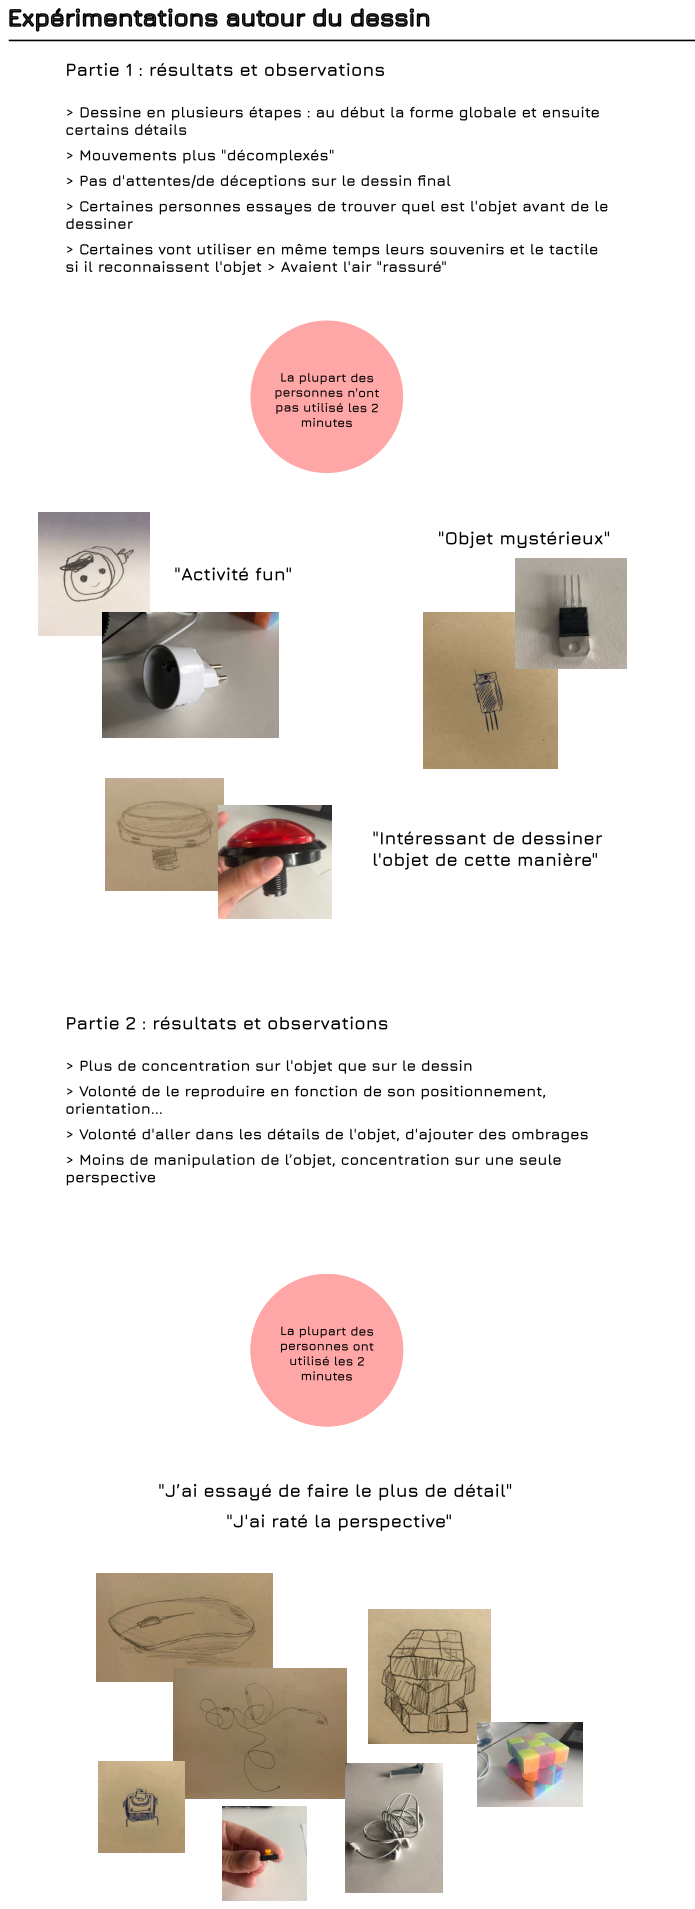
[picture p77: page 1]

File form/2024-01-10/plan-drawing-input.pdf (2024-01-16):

90

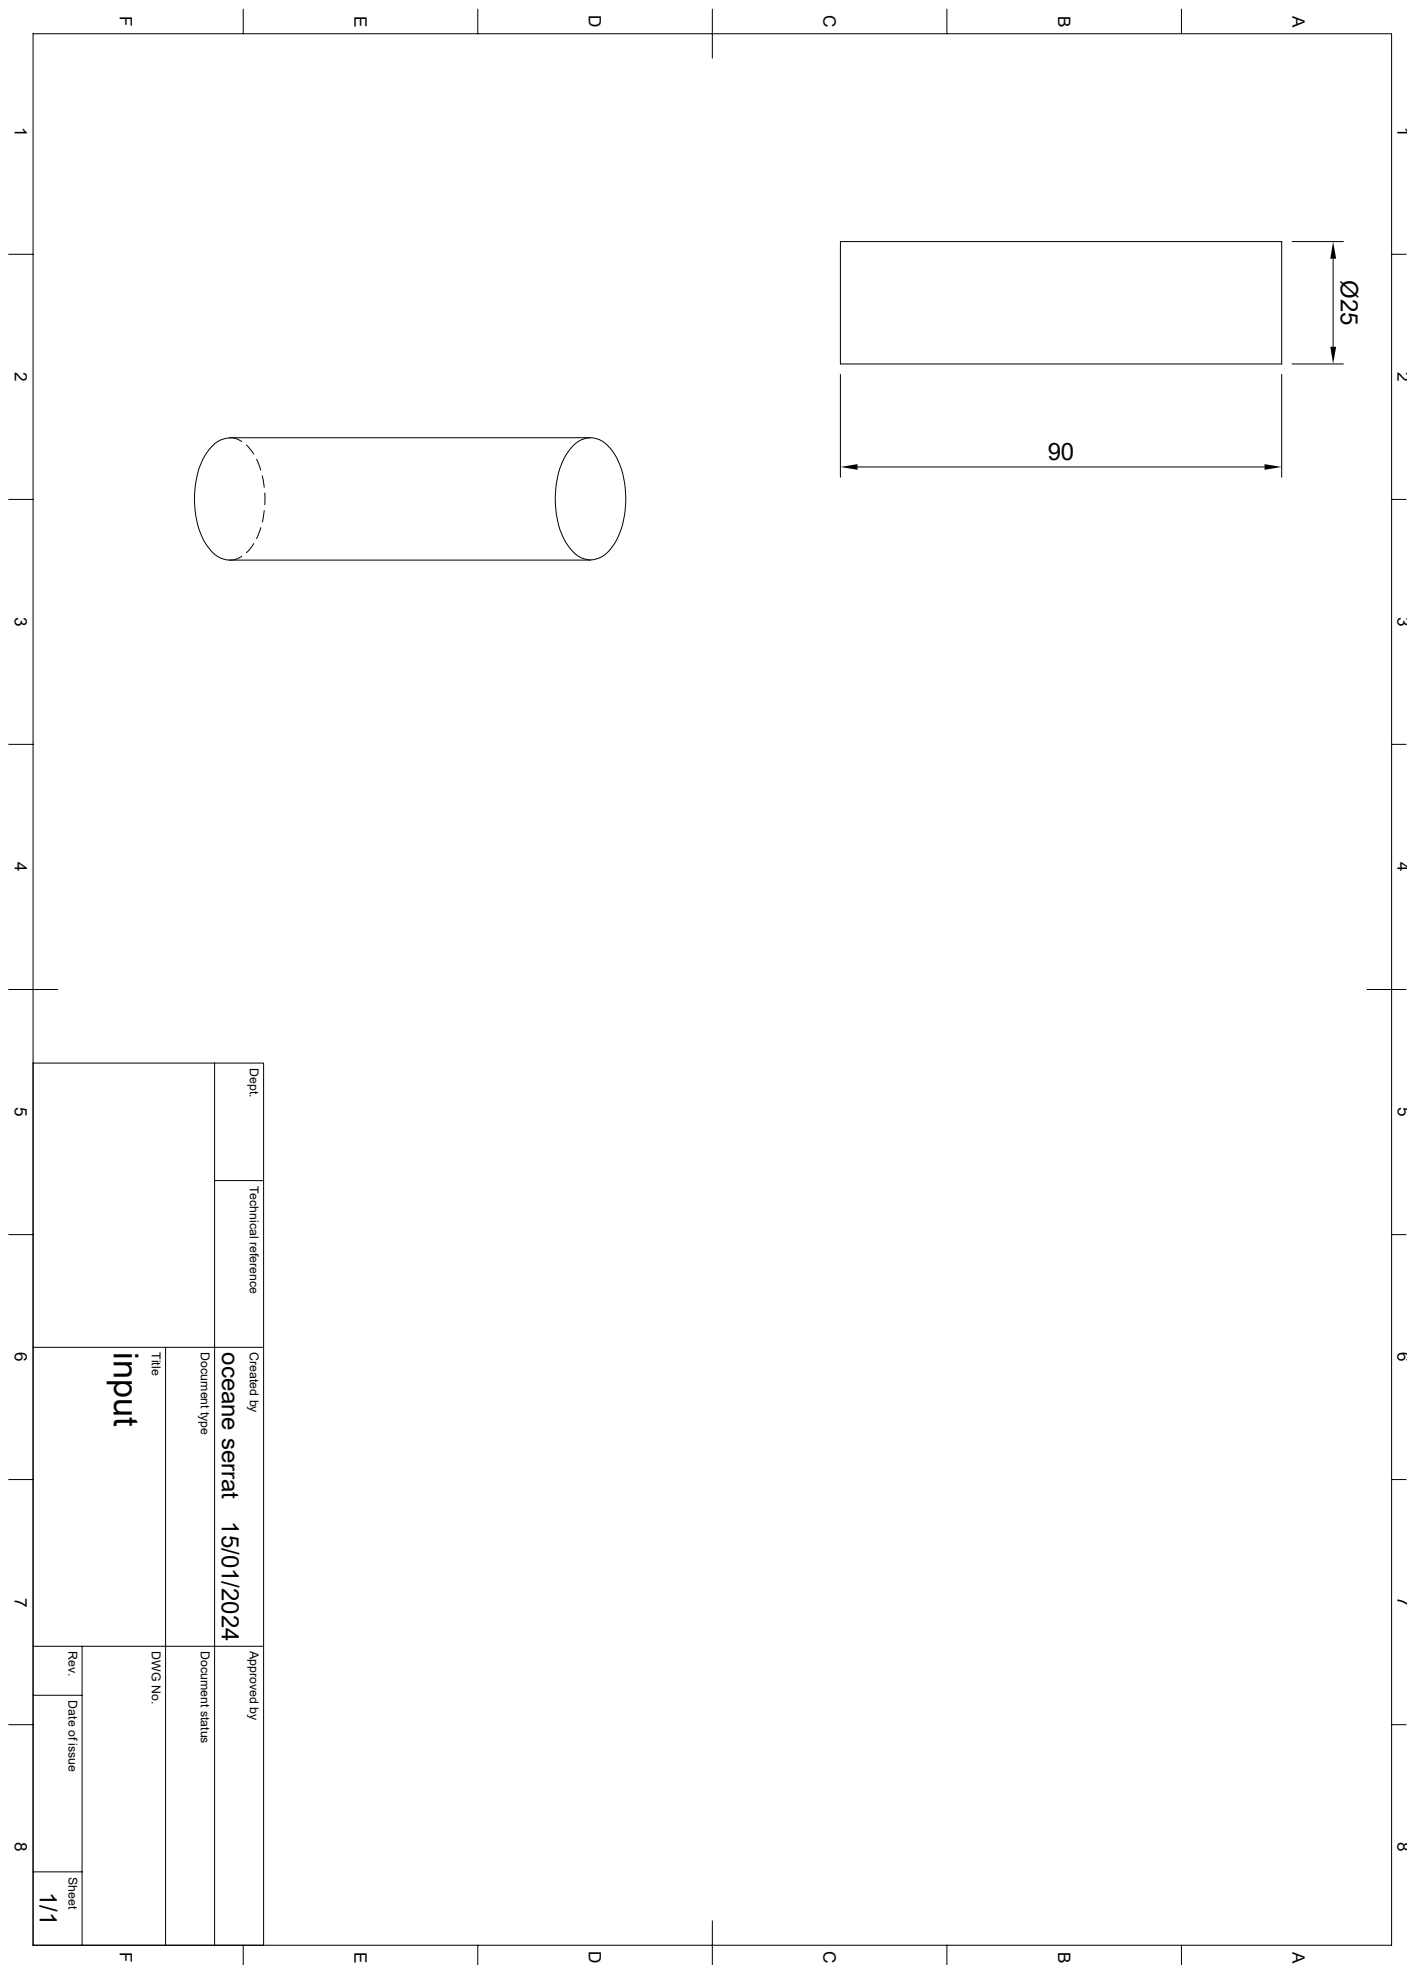
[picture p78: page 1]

1 A 2 3 4 5 6 7 8 1 2 3 4 5 6 7 8 FEDCB FEDCBA Dept. Technical reference Created by Approved by Title DWG No. Document type Document status Rev. Date of issue Sheet 15/01/2024 1/1 input oceane serrat Ø25

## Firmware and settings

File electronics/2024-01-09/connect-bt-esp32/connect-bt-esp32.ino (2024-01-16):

#include "BluetoothSerial.h"
#include <SPI.h>
#include <MFRC522.h>


#define VIBRATOR_PIN 15


BluetoothSerial SerialBT;

#define RST_PIN 12
#define SS_PIN 23

MFRC522 mfrc522(SS_PIN, RST_PIN);

void setup() {
  Serial.begin(115200);
  SerialBT.begin("ESP32test2");  // Bluetooth device name
  Serial.println("The device started, now you can pair it with Bluetooth!");


  pinMode(VIBRATOR_PIN, OUTPUT);

  while (!Serial);                                 // Do nothing if no serial port is opened (added for Arduinos based on ATMEGA32U4)
  SPI.begin();                        // Init SPI bus
  mfrc522.PCD_Init();                 // Init MFRC522
  delay(4);                           // Optional delay. Some board do need more time after init to be ready, see Readme
  mfrc522.PCD_DumpVersionToSerial();  // Show details of PCD - MFRC522 Card Reader details
  Serial.println(F("Scan PICC to see UID, SAK, type, and data blocks..."));
}


void loop() {
  lectureEnvoiRfid();

  vibrationBtEsp32();
  //delay(600);
}

void lectureEnvoiRfid() {
  if (!mfrc522.PICC_IsNewCardPresent()) {
    return;
  }

  // Select one of the cards
  if (!mfrc522.PICC_ReadCardSerial()) {
    return;
  }

  // Dump debug info about the card; PICC_HaltA() is automatically called
  //mfrc522.PICC_DumpToSerial(&(mfrc522.uid));
  // Ajouter un print pour afficher l'ID du tag RFID lu
  Serial.print("RFID Tag ID: ");
  for (byte i = 0; i < mfrc522.uid.size; i++) {
    Serial.print(mfrc522.uid.uidByte[i] < 0x10 ? " 0" : " ");
    Serial.print(mfrc522.uid.uidByte[i], HEX);
  }
  Serial.println();

  // Envoyer l'ID du tag RFID à la console de Processing via Bluetooth
  for (byte i = 0; i < mfrc522.uid.size; i++) {
    SerialBT.print(mfrc522.uid.uidByte[i] < 0x10 ? "0" : "");
    SerialBT.print(mfrc522.uid.uidByte[i], HEX);
  }
  SerialBT.println();  // Ajouter un saut de ligne pour séparer les données
  
}

void vibrationBtEsp32(){
  if (Serial.available()) {
    SerialBT.write(Serial.read());
  }


  if (SerialBT.available()) {
    // Lire la chaîne reçue via Bluetooth
    String bluetoothData = SerialBT.readStringUntil('\n');


    // Extraire l'intensité de vibration de la chaîne
    int index = bluetoothData.indexOf(':') + 1;
    String intensiteStr = bluetoothData.substring(index);
    int intensitevibration = intensiteStr.toInt();


    // Afficher les informations dans la console
    Serial.print("Bluetooth Data: ");
    Serial.println(bluetoothData);
    Serial.print("IntensiteVibration: ");
    Serial.println(intensitevibration);


    // Activer le moteur vibreur en fonction de l'intensité de vibration
    if (intensitevibration < 85) {
      // 1 vibration de 0.5 seconde
      digitalWrite(VIBRATOR_PIN, HIGH);
      delay(300);
      digitalWrite(VIBRATOR_PIN, LOW);


    } else if (85 < intensitevibration && intensitevibration <= 170) {
      // 2 vibrations avec un délai de 0.25 seconde entre les deux
      digitalWrite(VIBRATOR_PIN, HIGH);
      delay(200);
      digitalWrite(VIBRATOR_PIN, LOW);
      delay(200);
      digitalWrite(VIBRATOR_PIN, HIGH);
      delay(200);
      digitalWrite(VIBRATOR_PIN, LOW);
    } else {
      // 3 vibrations avec un délai de 0.25 seconde entre les trois
      digitalWrite(VIBRATOR_PIN, HIGH);
      delay(100);
      digitalWrite(VIBRATOR_PIN, LOW);
      delay(100);
      digitalWrite(VIBRATOR_PIN, HIGH);
      delay(100);
      digitalWrite(VIBRATOR_PIN, LOW);
      delay(100);
      digitalWrite(VIBRATOR_PIN, HIGH);
      delay(100);
      digitalWrite(VIBRATOR_PIN, LOW);
    }
  }
  delay(600);
}

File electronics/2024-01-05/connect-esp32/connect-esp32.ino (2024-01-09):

#include <WiFi.h>
#include <WebSocketsServer.h>
#include <ArduinoJson.h>

const char *ssid = "TP-Link_3AE9";     // Nom du réseau Wi-Fi
const char *password = "78354944"; // Mot de passe du réseau Wi-Fi

/*const char *ssid = "TP-Link_3AE9";     // Nom du réseau Wi-Fi
const char *password = "78354944"; // Mot de passe du réseau Wi-Fi*/

WebSocketsServer webSocket = WebSocketsServer(81); // Utilisez le port 81 pour les WebSockets

const int motorPin = 15;  // Broche à laquelle le moteur vibreur est connecté

void parseMouseData(String data) {
  DynamicJsonDocument jsonDocument(256);
  deserializeJson(jsonDocument, data);

  int mouseX = jsonDocument["x"];
  int mouseY = jsonDocument["y"];

  Serial.print("Position de la souris - X: ");
  Serial.print(mouseX);
  Serial.print(", Y: ");
  Serial.println(mouseY);

  // Traitement de la couleur RGB
  if (jsonDocument.containsKey("color")) {
    int redValue = jsonDocument["color"]["r"];
    int greenValue = jsonDocument["color"]["g"];
    int blueValue = jsonDocument["color"]["b"];

    // Calculer la valeur moyenne des composants RGB
    int averageColor = (redValue + greenValue + blueValue) / 3;

    // Ajuster l'intensité de vibration en fonction de la valeur moyenne de couleur
    int vibrationIntensity = map(averageColor, 0, 255, 0, 255);

    // Activer le moteur vibreur avec l'intensité calculée
    analogWrite(motorPin, vibrationIntensity);

    // Affichage sur le moniteur série (facultatif)
    Serial.print("Couleur RGB - R: ");
    Serial.print(redValue);
    Serial.print(", G: ");
    Serial.print(greenValue);
    Serial.print(", B: ");
    Serial.println(blueValue);
  }
}

void webSocketEvent(uint8_t num, WStype_t type, uint8_t *payload, size_t length) {
  switch (type) {
    case WStype_TEXT:
      String data = (char *)payload;
      parseMouseData(data);
      break;
  }
}

void setup() {
  Serial.begin(115200);
  delay(10);

  // Connecter l'ESP32 au réseau Wi-Fi
  WiFi.begin(ssid, password);
  while (WiFi.status() != WL_CONNECTED) {
    delay(1000);
    Serial.println("Connexion au WiFi en cours...");
  }
  Serial.println("Connecté au réseau WiFi");
  Serial.println(WiFi.localIP());

  // Démarrer le serveur WebSockets
  webSocket.begin();
  webSocket.onEvent(webSocketEvent);
  Serial.println("Serveur WebSockets démarré");

  // Configurer la broche du moteur vibreur en sortie
  pinMode(motorPin, OUTPUT);
}

void loop() {
  webSocket.loop();
  // Autres opérations si nécessaires
}

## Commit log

2023-10-31 images prototypes papiers premiere serie
2023-10-31 explications images prototypes
2023-10-31 images de rendus blender prototypes
2023-10-31 création de la mindmap initiale sur ce que "AI assistant" m'évoque
2023-10-31 journée des premiers prototypages papier
2023-10-31 creation de la premiere presentation des recherches (experimentations)
2023-11-01 Plan des différentes méthodes utilisées dans le processus
2023-11-12 ajout image fin test prototypes papier
2023-11-30 experimentations sur l'arduino
2023-11-30 tests arduino
2023-12-11 creation dossier exercice soudure
    [exercice-soudure.fzz]
2023-12-11 update 3D file form 1
    [forme1.f3d]
2023-12-12 update dimensions
    [forme2 v1.f3d]
2023-12-12 update formes et dimensions
    [forme2 v1.f3d, forme2 v3.obj]
2023-12-12 update formes
    [forme1 protopapier v1.f3d, forme3proto v3.f3d, forme4proto v2.f3d]
2023-12-19 Create forme-maj-2023-12-19-c-ache v3.f3d
    [forme-maj-2023-12-19-c-ache v3.f3d]
2023-12-20 MAJ electronique
    [test-print.stl]
2023-12-21 images print
2023-12-21 test composants et connexion esp32 - setup
2023-12-21 maj forme 3d fusion fichiers sources
    [forme-maj-2023-12-19-c-ache-bois v10.f3d, forme-maj-2023-12-19-c-ache-impression-3d v2.f3d, plateau-jeu-bois-c-ache v2.f3d]
2024-01-08 update electronics
    [partie-basse-pion.stl, partie-haute-pion.stl]
2024-01-08 creation projet esp32 arduino ide configuration virbreur
2024-01-10 update avancement
    [schemas.fzz]
2024-01-14 update all
    [furniture_wood_ad6a0617-35d7-4a5d-bb2d-331be68830e6.blend, orange_and_cyan_lights_1K_8cb9cf50-f612-46d2-9686-3e92447821f6.blend, pine_wood_2K_f99ce092-faaa-41e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]
2024-01-14 update presentation
    [boucle_fabric_43bba55f-74ad-4578-932d-5631b8d9e1b3.blend, free_3d_podium_ee931e97-4d22-4086-8d53-524b052752b4.blend, plastic_3d54c838-0a5a-415f-a3c1-6a13245ca0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]
2024-01-16 Clean dev log
    [schemas.fzz]
